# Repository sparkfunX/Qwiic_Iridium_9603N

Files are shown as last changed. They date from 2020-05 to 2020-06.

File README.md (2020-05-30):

# Qwiic Iridium 9603N

Iridium 9603N in Qwiic format (with I2C connectivity)

Qwiic Iridium 9603N (SPX-16394)

[Qwiic Iridium 9603N (SPX-16394)](https://www.sparkfun.com/products/16394)

## Repository Contents

- **/Hardware** - Eagle PCB, SCH and LBR design files
- **/Firmware** - Arduino code which comes pre-programmed onto the board
- **LEARN.md** contains a description of the Qwiic Iridium 9603N hardware
- **LICENSE.md** contains the licence information

## Arduino Examples

You will find a complete set of Arduino Examples for the Qwiic Iridium 9603N built into the [SparkFun IridiumSBD I2C Arduino Library](https://github.com/sparkfun/SparkFun_IridiumSBD_I2C_Arduino_Library).
Look for the [I2C_Examples__Qwiic_Iridium](https://github.com/sparkfun/SparkFun_IridiumSBD_I2C_Arduino_Library/tree/master/examples).

## Acknowledgements

This project relies upon [Spence Konde's ATTinyCore](https://github.com/SpenceKonde/ATTinyCore) for the ATtiny841.
Spence's work is gratefully acknowledged.

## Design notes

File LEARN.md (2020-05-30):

# Qwiic Iridium 9603N : LEARN

Qwiic Iridium 9603N (SPX-16394)

[Qwiic Iridium 9603N (SPX-16394)](https://www.sparkfun.com/products/16394)

## What is it?

The Qwiic Iridium 9603N is a breakout for the [Iridium 9603N Short Burst Data transceiver](https://www.iridium.com/products/iridium-9603/)
which can be used to send and receive _short_ messages (340 bytes transmitted, 270 bytes received) to and from _anywhere_ on Earth.

The 9603N has a serial (UART) interface which is great for many applications, but by no means all. The Qwiic Iridium 9603N uses an
[ATtiny841 AVR microcontroller](https://www.microchip.com/wwwproducts/en/ATTINY841) to bridge the serial interface to I2C,
allowing you to easily add Iridium communication to all Qwiic projects.

The key components of the Qwiic Iridium 9603N are:

## Iridium 9603N SBD Transceiver

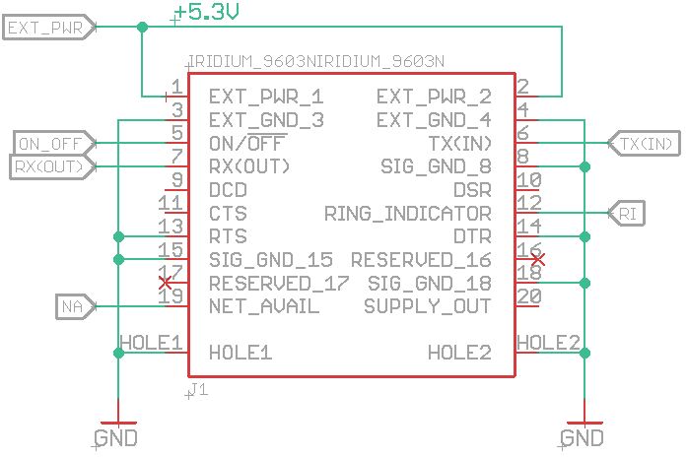
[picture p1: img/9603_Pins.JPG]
9603_Pins


The 9603N transceiver is a 5V device but has 3.3V serial (UART) and Input/Ouput pins. The serial interface uses an old-school "AT"
command set to send and receive messages. The I/O pins control its operation. The Qwiic Iridium 9603N connects to:

- Pins 1 & 2: these are connected to the 5.3V supply from the supercapacitors via the ADM4210 and N-FET.
- Pin 5: enables or disables the 9603N. High enables the 9603N, low disables it.
- Pin 6: is the serial data transmit _input_. The ATtiny841 serial transmit is connected to this pin.
- Pin 7: is the serial receive data _output_. This connects to the ATtiny841 serial receive pin.
- Pin 12: is the Ring Indicator. This pin will pulse low twice when a new 'Mobile Terminated' message is waiting to be downloaded.
- Pin 13: is the serial Request To Send input. This needs to be pulled low to allow serial communication to take place.
- Pin 14: is the serial Data Terminal Ready input. This too need to be pulled low.
- Pin 19: will be high when the Iridium network is available and the 9603N is able to receive the ring channel.

The ATtiny is connected to the I/O pins to form an I2C to serial bridge.

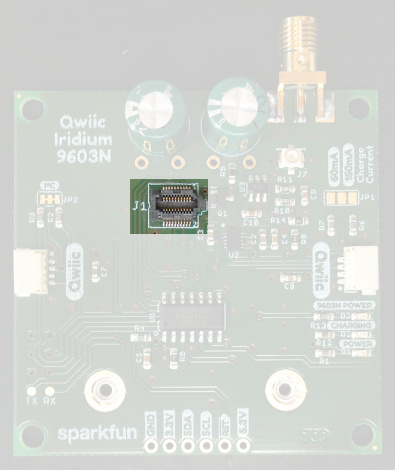
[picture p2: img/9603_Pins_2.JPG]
9603_Pins_2


The full AT command reference can be found [here](http://www.rock7mobile.com/downloads/IRDM_ISU_ATCommandReferenceMAN0009_Rev2.0_ATCOMM_Oct2012.pdf).

## LTC3225 Supercapacitor Charger and ADM4210 Current Limiter

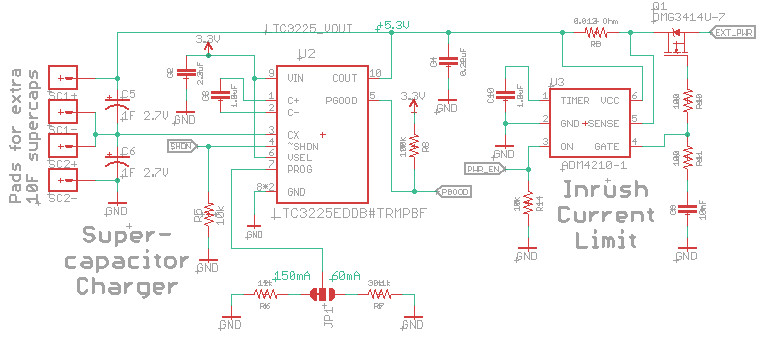
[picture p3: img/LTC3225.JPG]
LTC3225


The 9603N requires a power input of 5VDC +/- 0.5V. The power consumption at 5VDC is:

- 34mA average when idle
- 156mA peak when idle
- 39mA average during receive
- 156mA peak during receive
- 145mA average during transmit
- 1.3A peak during transmit
- The average current draw during a complete receive/transmit cycle is 158mA

The Qwiic Iridium 9603N uses an [LTC3225](https://www.analog.com/en/products/ltc3225.html) supercapacitor charger to meet these power needs.
When powered by 3.3V from the Qwiic interface, it charges a pair of supercapacitors to 5.3V. These capacitors deliver the 1.3A peak
current draw when the 9603N transmits.

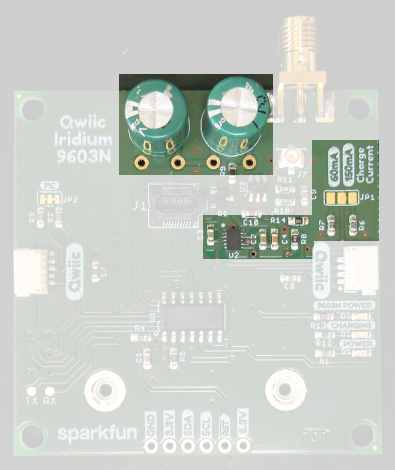
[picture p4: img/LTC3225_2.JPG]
LTC3225_2


The LTC3225 charge current is adjustable up to a maximum of 150mA. When set to the full 150mA, the LTC3225 can match the 145mA average current
drawn by the 9603N during transmit. This means that 1 Farad supercapacitors are adequate as they only need to hold enough charge to meet the
9603N's peak current draw during the very brief (8.3ms) transmit bursts.

The LTC3225 has an efficiency of approximately 75% when powered from 3.3V. This means the current drawn from the Qwiic interface is
approximately 200mA when charging the supercapacitors.

If you want to power the Qwiic Iridium 9603N from a low current source, e.g. solar panels, the charge current can be reduced to 60mA by
changing the JP1 jumper link. The current draw from the Qwiic interface falls to approximately 80mA. The 60mA charge current is enough
to offset the average current draw during receive, but bigger supercapacitors are needed to deliver the average current draw during a complete
receive/transmit cycle. So, if you do change the charge current to 60mA, you will also need to solder additional 10 Farad supercapacitors on to
the rear of the PCB using the solder pads provided.

The datasheet for the 9603N states that it can have a very low impedance when unpowered, leading to a large inrush current when the power is enabled.
The power supply circuit needs to limit the inrush current to a maximum of 4 Amps. To achieve this, the Qwiic Iridium 9603N uses an
[ADM4210-1](https://www.analog.com/en/products/adm4210.html) which can sense the current via R9 and limit it by changing Q1's Gate voltage.
The ADM4210 will limit the current when the voltage across R9 exceeds 50mV (4 Amps * 0.012 Ohms).

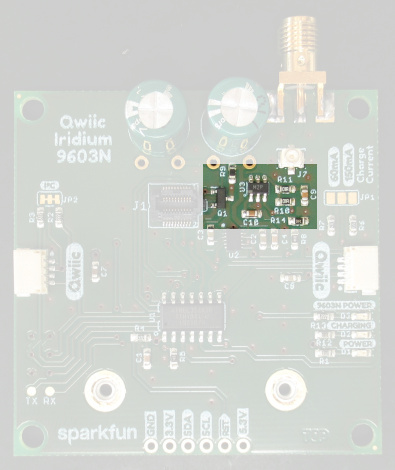
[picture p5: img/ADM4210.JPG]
ADM4210


The connections between the ATtiny841, LTC3225 and the ADM4210 are:

- !SHDN (LTC3225 Pin 6, ATtiny Pin 2) is used to enable or disable the LTC3225. Pulling this pin high enables it, low disables it.
- PGOOD (LTC3225 Pin 5, ATtiny Pin 5) goes high when the supercapacitors are 94% charged. This pin is used to illuminated LED D2; D2 lights up when the capacitors
are _charging_.
- PWR_EN (ADM4210 Pin 3, ATtiny Pin 10) is used to enable or disable the ADM4210. Pulling PWR_EN high enables power for the 9603N, low disables it.

The power-up sequence is:

- Enable the LTC3225 by pulling !SHDN high
- Wait until PGOOD goes high (LED D2 goes out)
- Enable 9603N power by pulling PWR_EN high

[The Iridium SBD I2C library](https://github.com/sparkfun/SparkFun_IridiumSBD_I2C_Arduino_Library) contains all of the functions you need to control the
Qwiic Iridium 9603N. The library contains several I2C examples including "Beacon_I2C" which demonstrates how to interface the Qwiic Iridium 9603N with
(e.g.) a [SparkFun SAM-M8Q breakout](https://www.sparkfun.com/products/15210)
or [ZOE-M8Q breakout](https://www.sparkfun.com/products/15193) to form an I2C GPS + Iridium beacon or tracker.

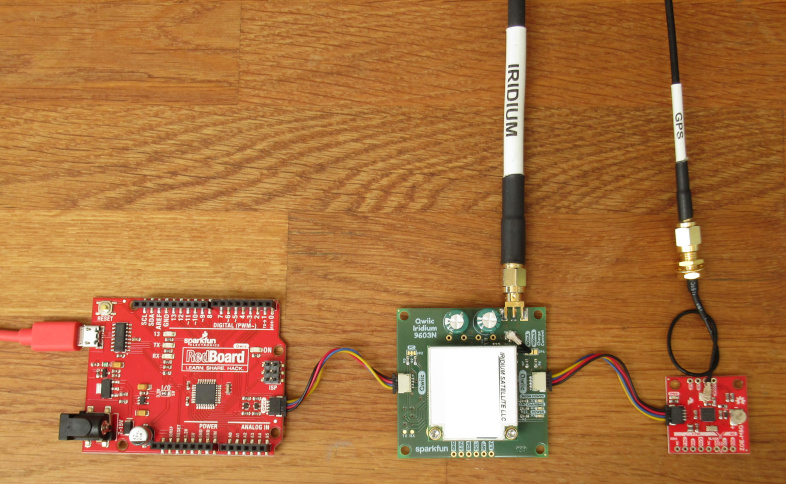
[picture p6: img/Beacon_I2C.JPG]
Beacon_I2C


The power control functions in the library are:

- _enableSuperCapCharger(true)_ will enable the LTC3225 by pulling !SHDN high
- _checkSuperCapCharger()_ will return true when PGOOD has gone high
- _enable9603Npower(true)_ will enable power for the 9603N by pulling PWR_EN high
- _enable841lowPower(true)_ will enable the ATtiny841's low power mode, substantially reducing the standby current

## ATtiny841

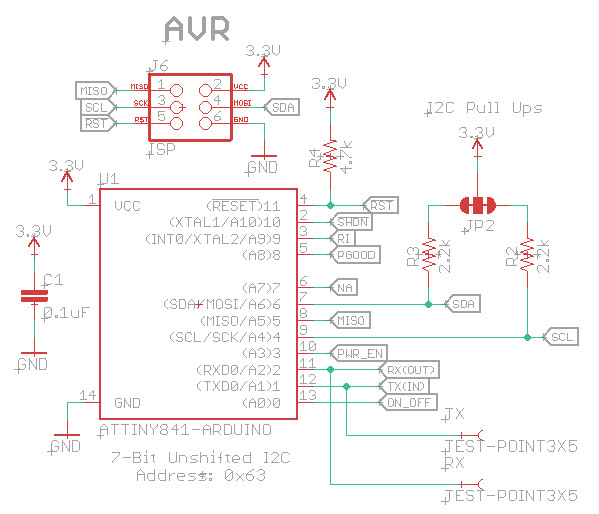
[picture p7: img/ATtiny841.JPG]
ATtiny841


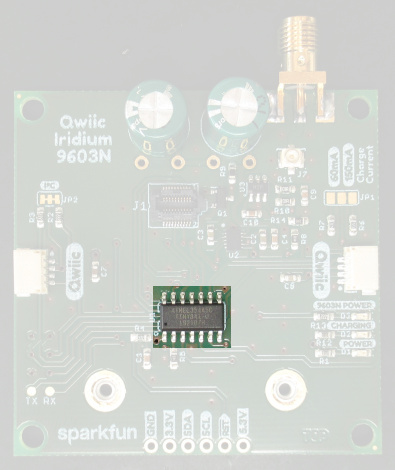
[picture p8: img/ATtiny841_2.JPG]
ATtiny841_2


The ATtiny841 is an enhanced version of the popular ATtiny84. It includes hardware support for both I2C and Serial which is vital when using it as an
I2C to Serial bridge. (Software serial isn't up to the job.)

Spence Konde has written a comprehensive library called [ATTinyCore](https://github.com/SpenceKonde/ATTinyCore) which provides full support for the ATtiny841.
You will need to use version 1.3.0 of the library (or later) as it includes
[one important fix](https://github.com/SpenceKonde/ATTinyCore/commit/0d17000a645234bb540b82086debf39ccb87f172) which the Qwiic Iridium 9603N needs.

[The Iridium SBD I2C library](https://github.com/sparkfun/SparkFun_IridiumSBD_I2C_Arduino_Library) contains high level functions which you can call to control and communicate with
the Qwiic Iridium 9603N. They do all of the heavy lifting for you. However, the following sections will be useful if you want to understand how the I2C interface works
so you can develop your own Wire functions should you want to.

## I2C (Wire) Interface

The Qwiic Iridium 9603N emulates a slave I2C device with a fixed address of 0x63. You can change the address but only by editing the
[Arduino firmware](Firmware/Qwiic_Iridium_9603N_ATtiny841/Qwiic_Iridium_9603N_ATtiny841.ino#L102).

The code in the ATtiny841 emulates three read/write 'registers':

- IO_REG (0x10) : the Input/Output register which is used to read and write the I/O pins
- LEN_REG (0xFD) : this register returns the number of bytes waiting to be read from the serial buffer. The buffer length is returned in MSB,LSB format.
- DATA_REG (0xFF) : this register allows serial data to be written to and read from the 9603N

### IO_REG

To read the I/O pins, the I2C Master needs to:

```
Wire.beginTransmission(0x63); // Open communication with the Qwiic Iridium 9603N
Wire.write(0x10); // Point to the IO register
Wire.endTransmission(); // Send data and release the bus
Wire.requestFrom(0x63, 1); // Request one byte from the IO register
if (Wire.available())
{
  uint8_t io_pins = Wire.read(); // Read the IO register
}
```

The WireS library for the 841 doesn't like it if the Master holds the bus between write and requestFrom, so don't use _endTransmission(false);_

The bit definitions for the IO_REG are:

- Bit 7: Not Used
- Bit 6: LOW_PWR - Read/Write - this bit enables/disables the ATtiny841's low power mode. Writing 1 to this bit enables low power mode
- Bit 5: PGOOD - Read Only - this bit will be high when the LTC3225 PGOOD signal is high
- Bit 4: NA - Read Only - this bit will be high when the 9603N Network Available pin is high
- Bit 3: RI - Read/Write - this bit is a flag which is set when the 9603N Ring Indicator pin pulses low. The flag can be cleared by writing a 0 to this bit
- Bit 2: ON_OFF - Read/Write - this bit controls the 9603N on/off pin (Pin 5). Writing a 1 to this bit enables the 9603N
- Bit 1: PWR_EN - Read/Write - this bit controls the PWR_EN signal which enables power to the 9603N via the ADM4210. Writing 1 to this bit enables the 9603N power
- Bit 0: SHDN - Read/Write - this bit controls the LTC3225 !SHDN signal to enable/disable the supercapacitor charger. Writing 1 to this bit enables the LTC3225

When writing to the IO_REG, you will need to use a read-modify-write approach: read the IO_REG, set or clear the appropriate bit(s), write the value back to the IO_REG.
E.g. to enable the LTC3225, the Master needs to:

```
Wire.beginTransmission(0x63); // Open communication with the Qwiic Iridium 9603N
Wire.write(0x10); // Point to the IO register
Wire.endTransmission(); // Send data and release the bus
Wire.requestFrom(0x63, 1); // Request one byte from the IO register
uint8_t io_pins = Wire.read(); // Read the IO register
io_pins |= 0x01; // Set the SHDN bit to enable the LTC3225
Wire.beginTransmission(0x63); // Open communication with the Qwiic Iridium 9603N
Wire.write(0x10); // Point to the IO register
Wire.write(io_pins); // Update the pins
Wire.endTransmission(); // Send data and release the bus
```

### LEN_REG

The serial length register indicates how many bytes are available in the Qwiic Iridium 9603N's serial buffer. The length is returned as two bytes in MSB,LSB format.

To read the buffer length, the I2C Master needs to:

```
uint16_t bytesAvailable = 0;
Wire.beginTransmission(0x63); // Open communication with the Qwiic Iridium 9603N
Wire.write(0xFD); // Point to the length register
Wire.endTransmission(); // Send data and release the bus
Wire.requestFrom(0x63, 2); // Request two bytes from the length register
if (Wire.available() >= 2)
{
  uint8_t msb = Wire.read(); // Read the length MSB
  uint8_t lsb = Wire.read(); // Read the length LSB
  bytesAvailable = (((uint16_t)msb) << 8) | (uint16_t)lsb; // Update bytesAvailable
}
```

Reading serial data from the DATA_REG needs to be done eight bytes at a time (if there are more than eight bytes available) due to limitations in the way the
way Wire.onRequest works. See below for details.

### DATA_REG

The serial data register is used to send data to and receive data from the 9603N.

To write serial data to the 9603N, the I2C Master simply needs to:

```
Wire.beginTransmission(0x63); // Open communication with the Qwiic Iridium 9603N
Wire.write(0xFF); // Point to the data register
Wire.print(str); // Write the string
Wire.endTransmission(); // Send data and release the bus
```

Take care not to send more than 32 bytes in one go or you will overflow the ATtiny's I2C buffer! Use multiple writes as required.

Reading serial data is a little more complex as the Wire.onRequest code in the ATtiny does not know how many bytes are being requested, simply that _some_ data is being requested.
For the Qwiic Iridium 9603N, we define that the Master will request data eight bytes at a time (if there are eight or more bytes available in the serial buffer).

A complete read cycle would be:

```
uint16_t bytesAvailable = 0;
Wire.beginTransmission(0x63); // Open communication with the Qwiic Iridium 9603N
Wire.write(0xFD); // Point to the length register
Wire.endTransmission(); // Send data and release the bus
Wire.requestFrom(0x63, 2); // Request two bytes from the length register
if (Wire.available() >= 2)
{
  uint8_t msb = Wire.read(); // Read the length MSB
  uint8_t lsb = Wire.read(); // Read the length LSB
  bytesAvailable = (((uint16_t)msb) << 8) | (uint16_t)lsb; // Update bytesAvailable
}
while (bytesAvailable > 8) // If there are more than 8 bytes waiting to be read
{
  Wire.requestFrom(0x63, 8); // Request 8 bytes from the data register
  while (Wire.available())
  {
    uint8_t data_byte = Wire.read(); // Read the data
    // Store the data byte
  }
  bytesAvailable -= 8; // Decrease bytesAvailable by 8
}
if (bytesAvailable > 0) // If there are some bytes waiting to be read
{
  Wire.requestFrom(0x63, bytesAvailable); // Request the remaining bytes from the data register
  while (Wire.available())
  {
    uint8_t data_byte = Wire.read(); // Read the data
    // Store the data byte
  }
}
```

The code in the ATtiny keeps its own copy of how many bytes were in the serial buffer when the length register was read, so it knows how many bytes to send
to the Master even if new serial data from the 9603N arrives part way through.

## ATTinyCore

The [Firmware folder](../../tree/master/Firmware) contains the code for the ATtiny841.

The Qwiic Iridium 9603N relies upon Spence Konde's [ATTinyCore](https://github.com/SpenceKonde/ATTinyCore) to provide support for the ATtiny841.

When compiling the code:
- Set Board to ATtiny441/841 (No bootloader)
- Set Chip to ATtiny841
- Set Clock to 8MHz(internal)
- Set BOD Level to BOD Enabled 1.8V
- Set BOD Mode (Active) and (Sleep) to BOD Disabled
- Set Save EEPROM to EEPROM Not Retained
- **Set Pin Mapping to Clockwise**
- **Set Wire Modes to Slave Only**
- Set millis()/micros():"Enabled" to Enabled

The ATtiny841 is delivered with the CKDIV8 bit programmed, which will make the 841 run at 1MHz instead of 8MHz. You will need to use (e.g.) AVRDUDESS to read and then
set the fuses to correct this:

- Set the L (Low) fuse byte to **0xC2**
- Set the H (High) fuse byte to 0xDF
- Set the E (Extended) fuse byte to 0xFF

Enjoy!

_Your friends at SparkFun_

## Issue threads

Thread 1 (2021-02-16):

3.3 V rail voltage drops during charging

adamgarbo, 2021-02-16:
Hi @PaulZC

I recently concluded a successful 11-day test of the Qwiic Iridium 9603N + MicroMod Data Logging Carrier Board + Artemis Processor. Temperatures in Canada were chilly again, dropping to -25°C, and it was a good opportunity to stress test the components in the cold.

I realized I had never measured the voltage of the 3.3 V rail when the Qwiic Iridium was powering up. I was surprised to see that when charging (@ 150 mA), the Qwiic Iridium hammers the 3.3 V bus, causing it to drop to 2.9 V. I observed the same behaviour when connected to both an MMDLCB (powered by a 3.7 V LiPo) and a Qwiic Micro (3.3 V rail powered by a SparkFun Buck-Boost).

Is this expected behaviour for the Qwiic Iridium 9603N? If so, do you anticipate this voltage drop would cause any issues for other devices on the I2C bus? 

Cheers,
Adam

PaulZC, 2021-02-17:
Hi Adam (@adamgarbo ),
Thanks for letting me know. I will dig into this as soon as time permits.
Best wishes,
Paul

adamgarbo, 2021-02-19:
Thanks, @PaulZC!

I should note that I'm encountering this issue with V1 of the Qwiic Iridium 9603N. Did the power circuity change in V2?

Cheers,
Adam

adamgarbo, 2021-02-19:
A quick test with a SparkFun Qwiic Micro + Qwiic Iridium 9603N. The 3.3 V rail is powered by a SparkFun BuckBoost connected to a 12 V battery.

The Buck-Boost can output up to 2 A, which the Qwiic Iridium should never get close to. Same behaviour observed with a Pololu 3.3V 600 mA step-down regulator.

Putting it on scope reveals there is definitely something strange going on.

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

PaulZC, 2021-02-20:
Hi @adamgarbo ,
Thanks for this.
I wouldn't describe the trace as 'strange'. That's exactly what I would expect to see. A long period of capacitor charging, followed by short bursts of capacitor charging while the Iridium modem is on but not transmitting, followed by a longer burst to top the capacitors back up during and after the transmission.
What is unexpected is the size of the voltage drop. I would have expected it to be much smaller than that.
How are you connecting everything? Qwiic cable? Hard-soldered wires/connectors? Or breadboard + jumper wires?
I will dig into this when I get time - promise.
Best wishes,
Paul

adamgarbo, 2021-02-20:
Hi @PaulZC,

I agree! The output of the oscilloscope is expected, but not the magnitude of the voltage drops. I just finished performing a dozen tests of different combinations of components and will update this comment once I finish reviewing the data. The two biggest culprits right now are the [SparkFun breadboards](https://www.sparkfun.com/products/12615) I recently purchased and the Qwiic Power Switch. When everything is connected directly through Qwiic cables, the voltage drop issues seem to disappear, unless the Qwiic Iridium 9603N is behind the Qwiic Power Switch.

Cheers,
Adam

adamgarbo, 2021-02-21:
Hi @PaulZC,

Well, I think I've had enough of measuring voltages! Based on the graphs shown below, I believe we can draw a few main conclusions:

1) The Qwiic Iridium 9603N should never be placed behind the Qwiic Power Switch. This results in the most significant voltage drops (Tests 1, 2, 5, 6).
2) The SparkFun Buck-Boost does not appear to be suitable for replacing the Qwiic Micro's AP2112 regulator. It does not handle the load of the Qwiic Iridium 9603N (or RockBLOCK) very well. The 5V USB battery and AP2112 LDO results in a much stabler voltage (see Test 8)
3) The SparkFun Breadboard is also causing increased voltage drops when compared to using the Qwiic connectors, even with minimal length 22 AWG jumper wires. Tests 4 vs 8 is a good example of this.

Based on these test results, I don't believe there's actually any issue with Qwiic Iridium 9603N. The problem is really with everything else!

I'm a little worried that because I don't see a ring carrier signal that the current draw of the Qwiic Iridium 9603N may not be reflective of a real work scenario, so I may try measuring the voltage outside in the snow.

I'll leave this issue open until I perform the same tests on the MicroMod Data Logging Carrier Board. I suspect I'll encounter much the same results.

Cheers,
Adam

## Test Configuration

All tests used the following SparkFun Qwiic components:
* Qwiic Micro SAMD21
* RV8803 RTC
* BME280
* Qwiic Power Switch
* SAM-M8Q
* Qwiic Iridium 9603N

**Circuit design/wiring:**
1. SparkFun breadboard and 22 AWG jumper wires cut to a minimum length, or
2. Qwiic connectors

**Power sources:**
1. SparkFun Buck-Boost @3.3V powered from 12 V battery connected directly to 3.3V rail
2. 10 Ah 5V USB battery connected direcly to Qwiic Micro's USB port (uses AP2112 LDO)

**Measurements:**
* PicoScope 4227 oscilloscope
* Channel A (blue): 3.3 V rail or directly on Qwiic 3.3V/GND pins
* Channel B (red): 3.3V/GND pins of Qwiic Iridium 9603N
* Oscilloscope output saved to CSV and plotted in Python

**Test 1:**
* Buck-Boost @3.3V
* SparkFun breadboard + jumper wires
* Qwiic Iridium 9603N behind Qwiic Power Switch (QPS)
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

**Test 2:**
* 5V USB battery
* SparkFun breadboard + jumper wires
* Qwiic Iridium 9603N behind QPS
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

**Test 3:**
* Buck-Boost @3.3V
* SparkFun breadboard + jumper wires
* Qwiic Iridium 9603N in front QPS
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

**Test 4:**
* 5V USB battery
* SparkFun breadboard + jumper wires
* Qwiic Iridium 9603N in front QPS
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

**Test 5:**
* Buck-Boost @3.3V
* Qwiic connectors
* Qwiic Iridium 9603N behind QPS
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

**Test 6:**
* 5V USB battery
* Qwiic connectors
* Qwiic Iridium 9603N behind QPS
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

**Test 7:**
* Buck-Boost @3.3V
* Qwiic connectors
* Qwiic Iridium 9603N in front of QPS
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

**Test 8:**
* 5V USB battery
* Qwiic connectors
* Qwiic Iridium 9603N in front of QPS
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

PaulZC, 2021-02-22:
Hi Adam (@adamgarbo ),
Nice very methodical work! ;-) Thank you.
The Qwiic Power Switch drop is a surprise. The breadboard + jumpers less so. (Think about the **tiny** contact area between the breadboard 'fingers' or 'jaws' and your solid-core jumper wires.)
The QPS uses a DMG2305 P-FET and looking at the datasheet the R<sub>DS(ON)</sub> varies with both temperature and V<sub>GS</sub>. But I would expect it to be around 50mOhms at 3.3V and room temperature. If the Qwiic Iridium is drawing around 300mA (roughly double the charging current), the voltage drop across the FET should be around 15mV, not ~ten times that... Maybe we're not driving the gate hard enough? I wonder what would happen if R5 were changed to 100R or 10R?
I will investigate when I get time, but like you say, the Qwiic Iridium itself appears to be behaving as expected.
Thanks!
Paul

adamgarbo, 2021-02-22:
Thanks, Paul!

I'm happy to create a separate issue on the QPS repository but it's not a high priority.

Regarding wiring, wouldn't the "jaws" of the breadboard technically have more surface area contact with the AWG 22 jumper wire than the Qwiic JST connector/28 AWG wire? SparkFun doesn't have any information on the max current rating of their breadboards, but I would expect that they should be able to handle ~0.3 A without any difficulty. Given this, I suspect that the breadboard is also the cause of the problems I was having when trying to power a RockBLOCK at ~450 mA.

Cheers,
Adam

Closed 2021-02-22.

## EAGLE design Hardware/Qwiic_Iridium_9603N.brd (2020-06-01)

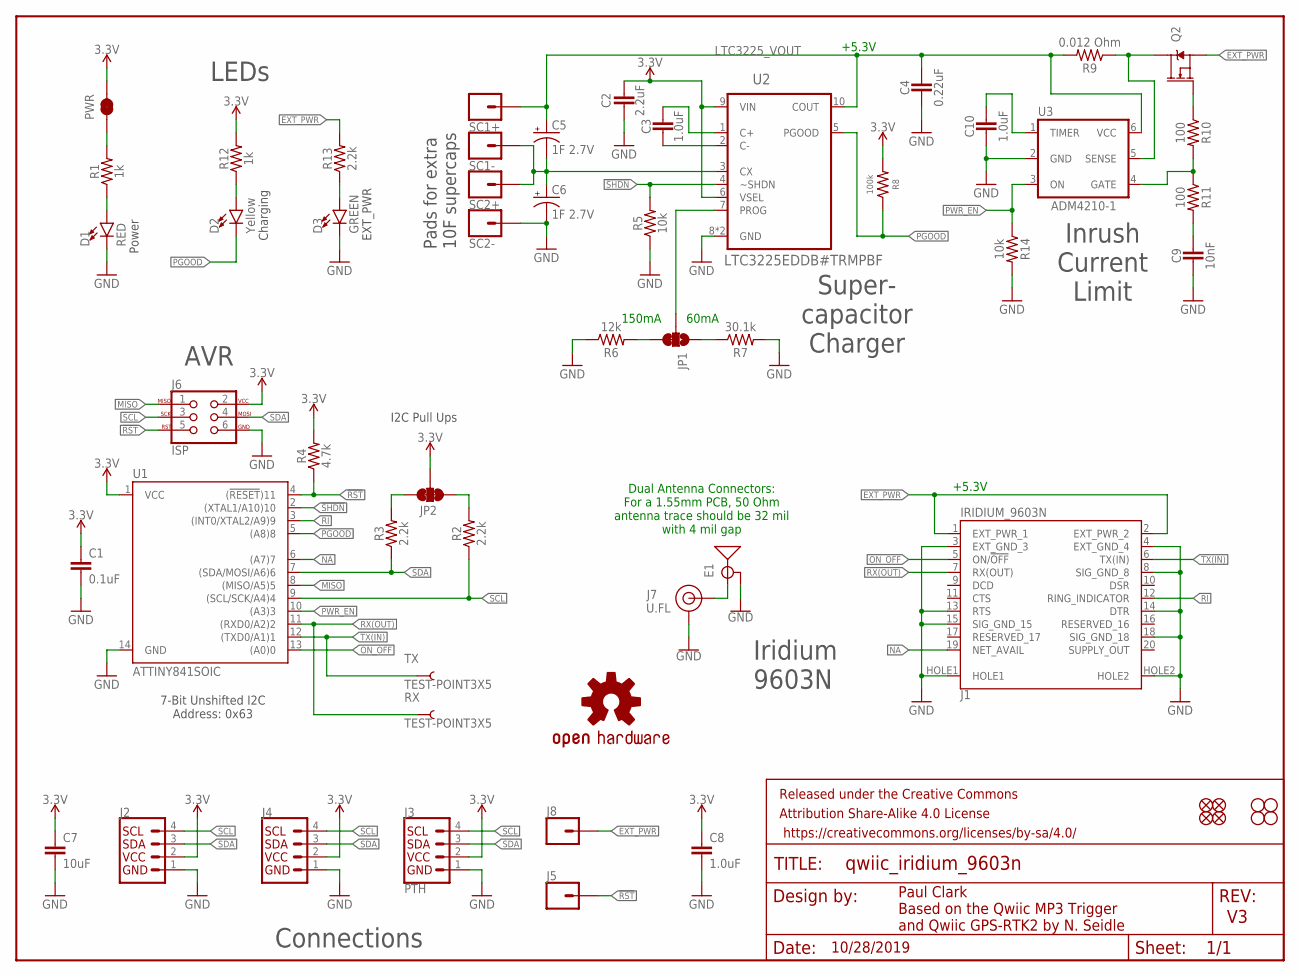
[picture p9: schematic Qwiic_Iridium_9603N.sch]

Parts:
C1: 0.1uF; 0603
C2: 2.2uF; 0603
C3, C8, C10: 1.0uF; 0603
C4: 0.22uF; 0603
C5, C6: 1F 2.7V; CPOL-RADIAL-1F-2.7V
C7: 10uF; 0603
C9: 10nF; 0603
D1: RED; LED-0603
D2: Yellow; LED-0603
D3: GREEN; LED-0603
E1: ANTENNA-GROUNDEDEDGE_SMA; SMA-EDGE
FRAME1: FRAME-LETTER; CREATIVE_COMMONS
J1: IRIDIUM_9603N
J2, J4: QWIIC_CONNECTORJS-1MM; JST04_1MM_RA
J3: PTH; 1X04_NO_SILK
J5, J8: CONN_01PTH_NO_SILK_YES_STOP; 1X01_NO_SILK
J6: ISP; 2X3_TEST_POINTS
J7: U.FL
JP1: JUMPER-SMT_3_1-NC_TRACE_SILK; SMT-JUMPER_3_1-NC_TRACE_SILK
JP2: JUMPER-SMT_3_2-NC_TRACE_SILK; SMT-JUMPER_3_2-NC_TRACE_SILK
JP3, JP4, JP9, JP10: STAND-OFF
JP5, JP6, JP7, JP8: FIDUCIAL1X2; FIDUCIAL-1X2
LOGO1: OSHW-LOGOMINI; OSHW-LOGO-MINI
PWR: JUMPER-SMT_2_NC_TRACE_SILK; SMT-JUMPER_2_NC_TRACE_SILK
Q2: 5.8A/30V/35mΩ; SOT23-3
R1, R12: 1k; 0603
R2, R3, R13: 2.2k; 0603
R4: 4.7k; 0603
R5, R14: 10k; 0603
R6: 12k; 0603
R7: 30.1k; 0603
R8: 100k; 0603
R9: 0.012 Ohm; 0603
R10, R11: 100; 0603
RX: TEST-POINT3X5; PAD.03X.05
SC1+, SC1-, SC2+, SC2-: CONN_01PTH_NO_SILK_YES_STOP; 1X01_NO_SILK
TX: TEST-POINT3X5; PAD.03X.05
U1: ATTINY841SOIC; ATTINY841
U2: LTC3225EDDB#TRMPBF; DFN300X200-10L
U3: ADM4210-1; TSOT6

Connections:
3.3V: C1.1, C2.1, C7.1, C8.1, J2.2, J3.2 (VCC), J4.2, J6.2, JP2.2, PWR.2, R4.2, R8.2, R12.2, U1.1 (VCC), U2.6 (VSEL), U2.9 (VIN)
!RST: J5.1, J6.5, R4.1, U1.4 ((!RESET!)11)
!SHDN: R5.2, U1.2 ((XTAL1/A10)10), U2.4 (~SHDN)
EXT_PWR: J1.1 (EXT_PWR_1), J1.2 (EXT_PWR_2), J8.1, Q2.2 (S), R13.2
GND: C1.2, C2.2, C4.2, C6.-, C7.2, C8.2, C9.2, C10.2, D1.C, D3.C, E1.GND@0 (GND), E1.GND@1 (GND), E1.GND@2 (GND), E1.GND@3 (GND), J1.3 (EXT_GND_3), J1.4 (EXT_GND_4), J1.8 (SIG_GND_8), J1.13 (RTS), J1.14 (DTR), J1.15 (SIG_GND_15), J1.18 (SIG_GND_18), J1.HOLE1, J1.HOLE2, J2.1, J3.1 (GND), J4.1, J6.6, J7.1 (GND), J7.2 (GND), R5.1, R6.1, R7.2, R14.2, SC2-.1, U1.14 (GND), U2.8 (GND), U2.11 (GND), U3.2 (GND)
LTC3225_VOUT: C4.1, C5.+, R9.2, SC1+.1, U2.10 (COUT), U3.6 (VCC)
MISO: J6.1, U1.8 ((MISO/A5)5)
unnamed: C5.-, C6.+, SC1-.1, SC2+.1, U2.3 (CX)
unnamed: JP1.3, R6.2
unnamed: D1.A, R1.1
unnamed: JP1.1, R7.1
unnamed: D2.A, R12.1
unnamed: D3.A, R13.1
unnamed: E1.SIG (SIGNAL), J7.FEED (SIGNAL)
unnamed: Q2.3 (D), R9.1, U3.5 (SENSE)
unnamed: C3.2, U2.2 (C-)
unnamed: C3.1, U2.1 (C+)
unnamed: JP1.2, U2.7 (PROG)
unnamed: Q2.1 (G), R10.1
unnamed: R10.2, R11.1, U3.4 (GATE)
unnamed: C9.1, R11.2
unnamed: C10.1, U3.1 (TIMER)
unnamed: PWR.1, R1.2
NA: J1.19 (NET_AVAIL), U1.6 ((A7)7)
ON_OFF: J1.5 (ON/!OFF!), U1.13 ((A0)0)
PGOOD: D2.C, R8.1, U1.5 ((A8)8), U2.5 (PGOOD)
PWR_EN: R14.1, U1.10 ((A3)3), U3.3 (ON)
RI: J1.12 (RING_INDICATOR), U1.3 ((INT0/XTAL2/A9)9)
RX(OUT): J1.7 (RX(OUT)), RX.P$1, U1.11 ((RXD0/A2)2)
SCL: J2.4, J3.4 (SCL), J4.4, J6.3, R2.1, U1.9 ((SCL/SCK/A4)4)
SCL_PU1: JP2.1, R2.2
SDA: J2.3, J3.3 (SDA), J4.3, J6.4, R3.1, U1.7 ((SDA/MOSI/A6)6)
SDA_PU1: JP2.3, R3.2
TX(IN): J1.6 (TX(IN)), TX.P$1, U1.12 ((TXD0/A1)1)

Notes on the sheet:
Paul Clark Based on the Qwiic MP3 Trigger and Qwiic GPS-RTK2 by N. Seidle
Power
7-Bit Unshifted I2C Address: 0x63
I2C Pull Ups
AVR
Connections
+5.3V
150mA
60mA
Pads for extra 10F supercaps
Super- capacitor Charger
Charging
EXT_PWR
Iridium 9603N
Dual Antenna Connectors: For a 1.55mm PCB, 50 Ohm antenna trace should be 32 mil with 4 mil gap
LEDs
Inrush Current Limit
10/28/2019

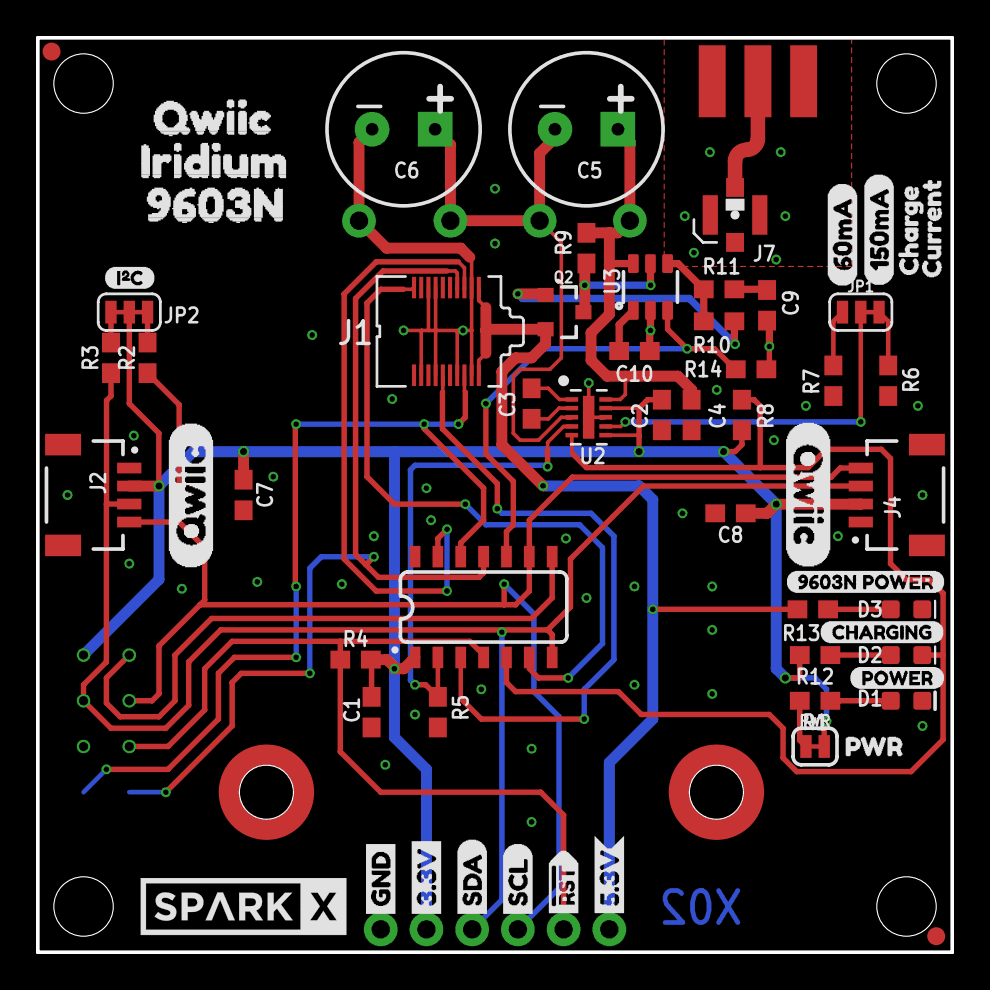
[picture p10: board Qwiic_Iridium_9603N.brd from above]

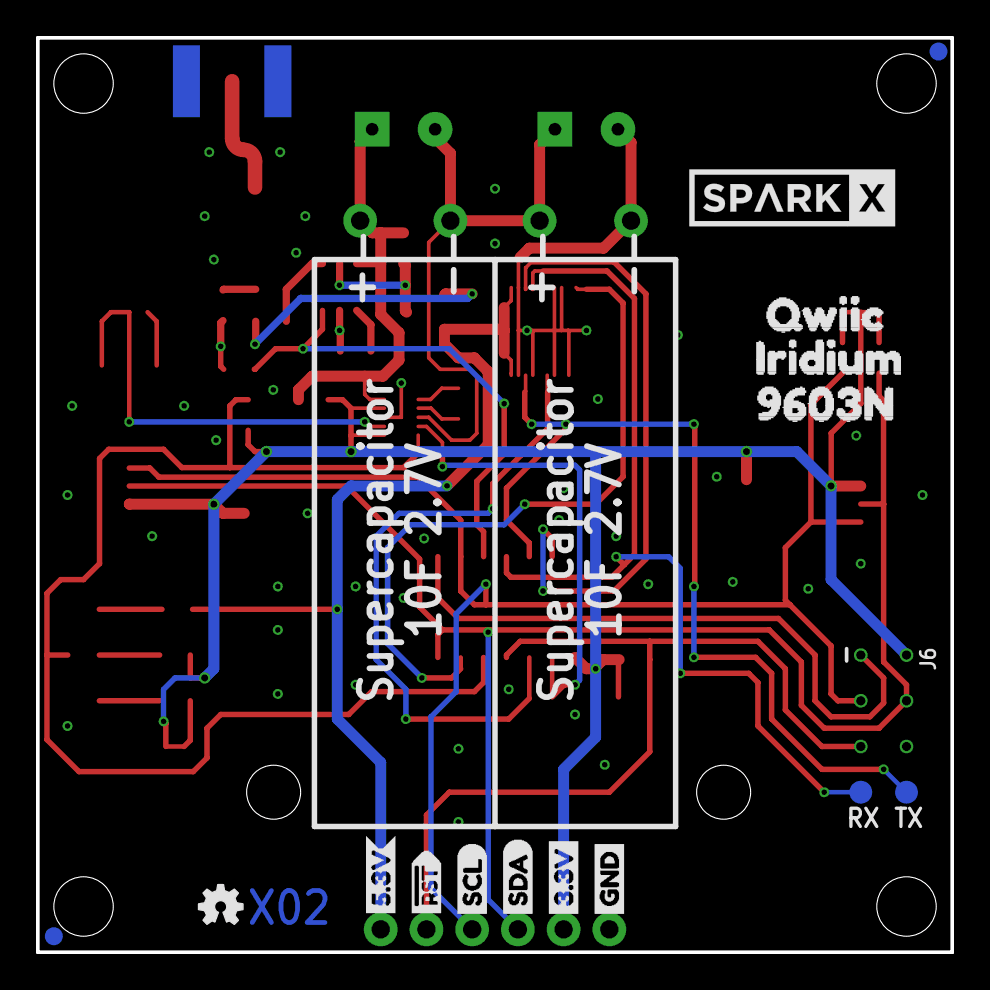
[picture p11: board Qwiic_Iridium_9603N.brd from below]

Board: 2 copper layers, 50.8 x 50.8 mm, 90 parts (16 on the bottom side), 34 nets.

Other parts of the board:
U$1: 60MA0
U$2: POWER0
U$3, U$22: GND1
U$4, U$21: 3#3V2
U$5, U$27: SDA8
U$6, U$26: SCL9
U$7, U$16: RST#-[>
U$8: I_SUPER2_C-()-03
U$9: CHARGING0
U$10: 9603N_POWER0
U$11, U$32: 5#3V0
U$12, U$17, U$23, U$25: QWIIC0
U$13: 150MA0
U$14: CHARGE0
U$15: CURRENT0
U$18, U$19: IRIDIUM0
U$20, U$24: 9603N0
U$29, U$30: SPARKX-LARGE
U$31: _PWR1

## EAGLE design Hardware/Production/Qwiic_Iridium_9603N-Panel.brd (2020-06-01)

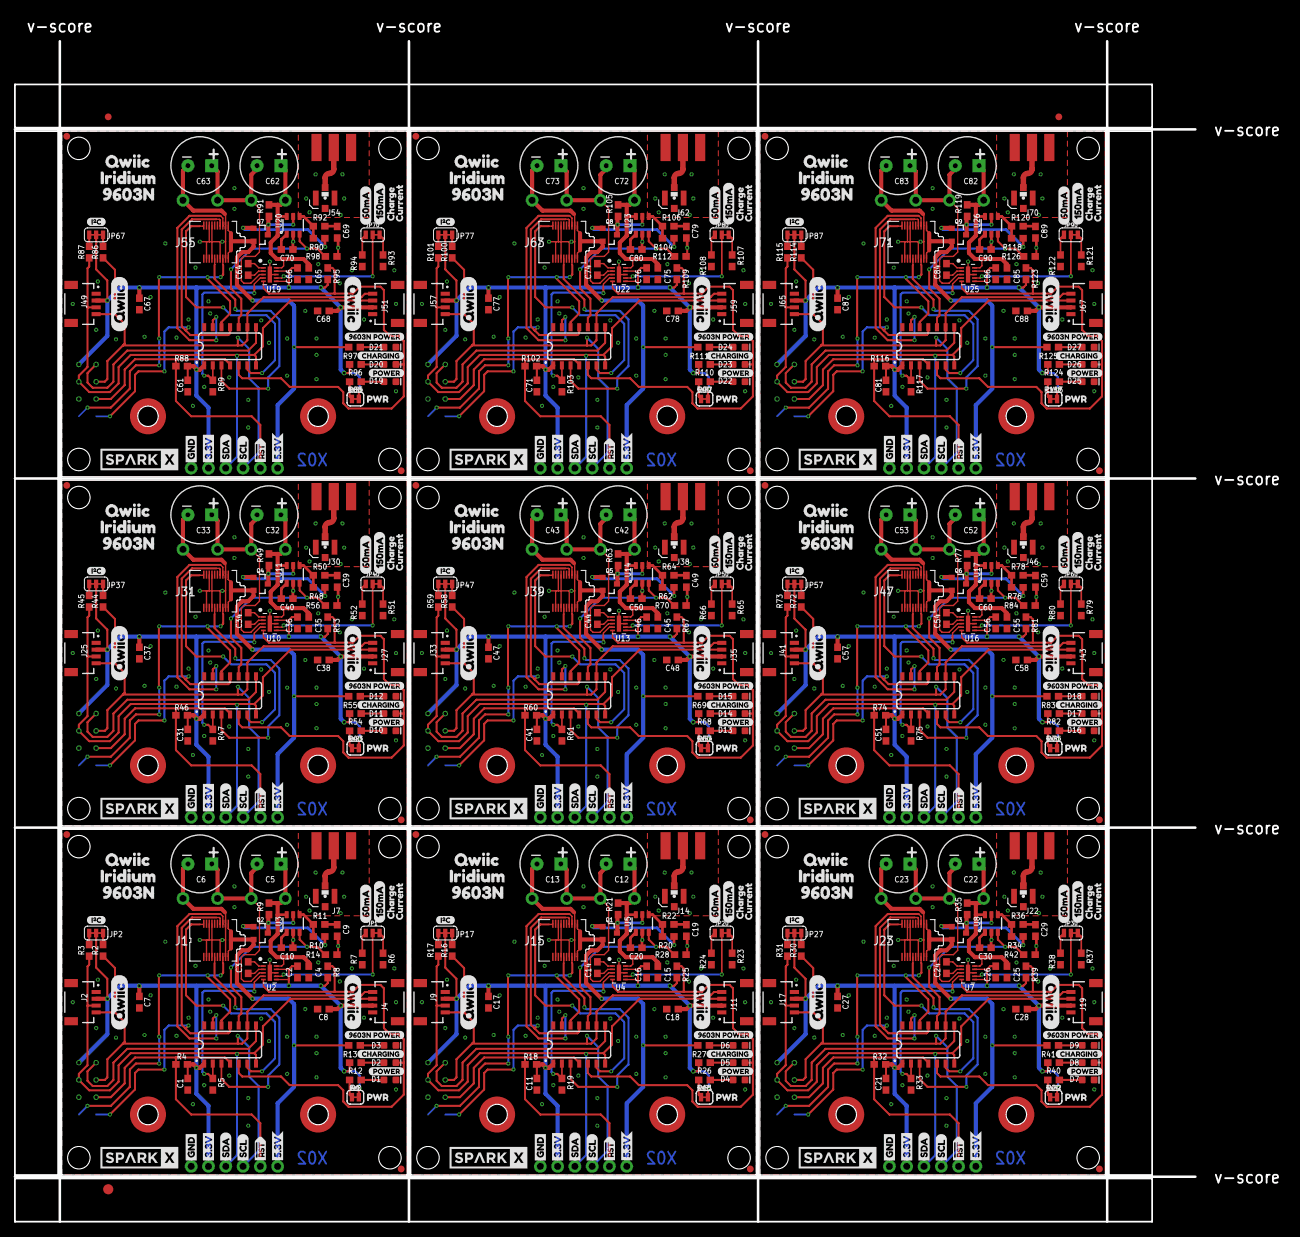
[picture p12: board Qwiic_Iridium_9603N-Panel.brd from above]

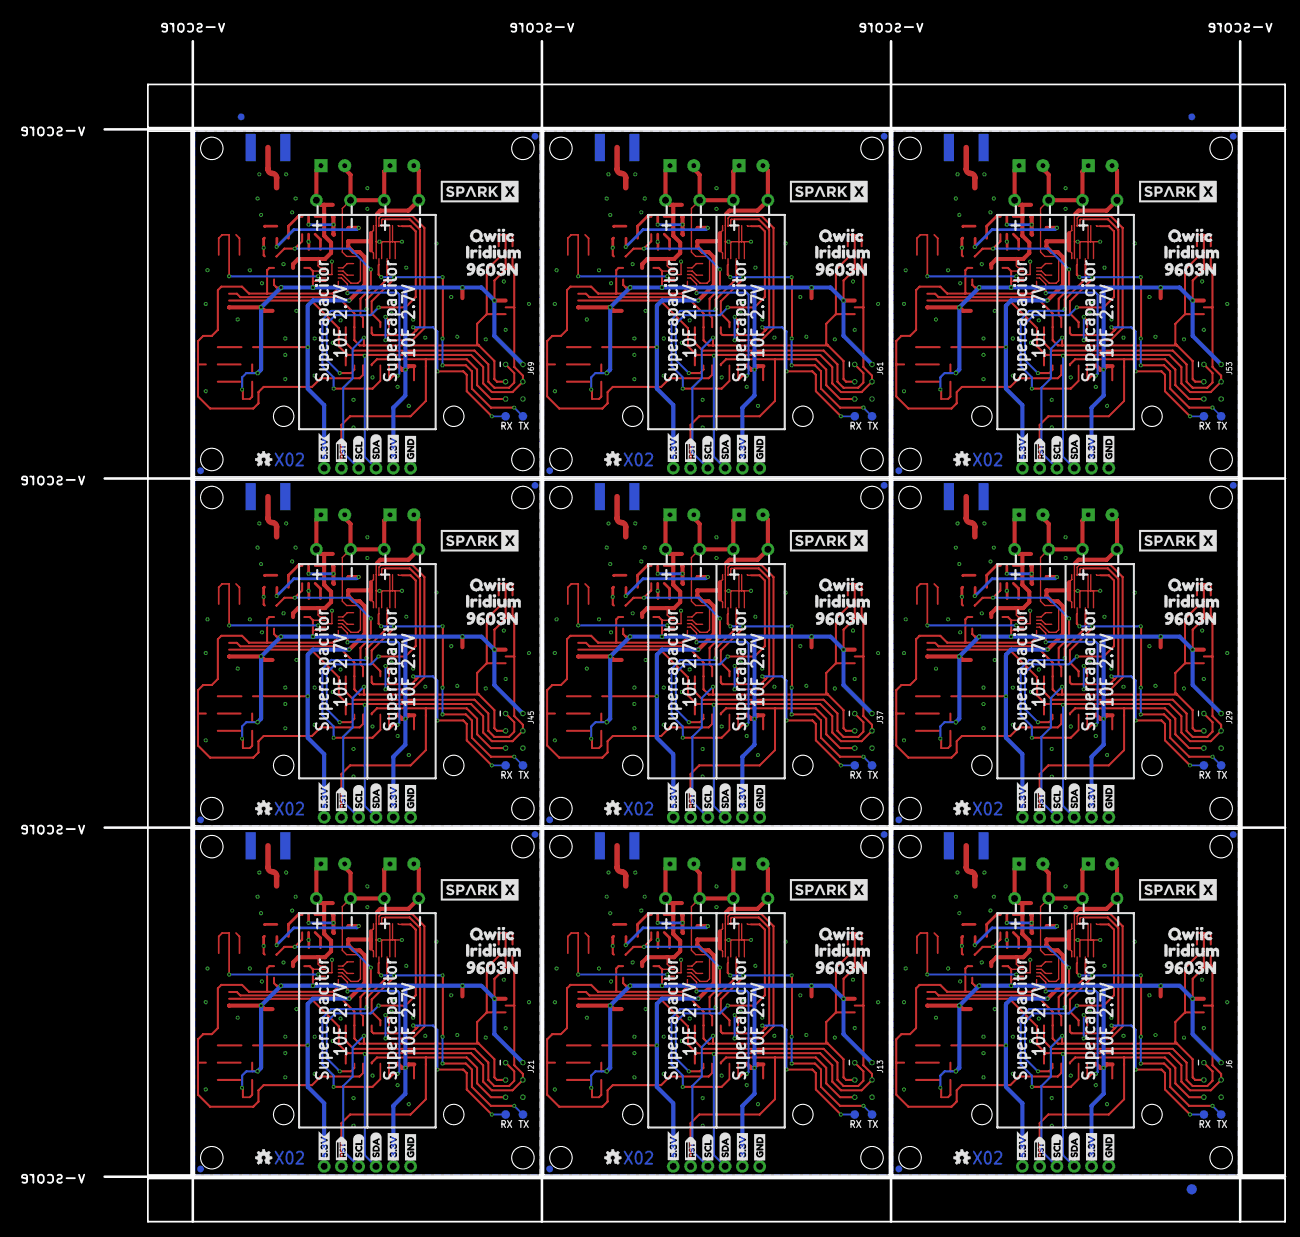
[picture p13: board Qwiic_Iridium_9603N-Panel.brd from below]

Board: 2 copper layers, 173.5 x 173.5 mm, 807 parts (147 on the bottom side), 306 nets.

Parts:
C1, C11, C21, C31, C41, C51, C61, C71, C81: 0.1uF; 0603
C2, C16, C26, C36, C46, C56, C66, C76, C86: 2.2uF; 0603
C3, C8, C10, C14, C18, C20, C24, C28, C30, C34, C38, C40, C44, C48, C50, C54, C58, C60, C64, C68, C70, C74, C78, C80, C84, C88, C90: 1.0uF; 0603
C4, C15, C25, C35, C45, C55, C65, C75, C85: 0.22uF; 0603
C5, C6, C12, C13, C22, C23, C32, C33, C42, C43, C52, C53, C62, C63, C72, C73, C82, C83: 1F 2.7V; CPOL-RADIAL-1F-2.7V
C7, C17, C27, C37, C47, C57, C67, C77, C87: 10uF; 0603
C9, C19, C29, C39, C49, C59, C69, C79, C89: 10nF; 0603
D1, D4, D7, D10, D13, D16, D19, D22, D25: RED; LED-0603
D2, D5, D8, D11, D14, D17, D20, D23, D26: Yellow; LED-0603
D3, D6, D9, D12, D15, D18, D21, D24, D27: GREEN; LED-0603
E1, E2, E3, E4, E5, E6, E7, E8, E9: ANTENNA-GROUNDEDEDGE_SMA; SMA-EDGE
E$1, E$2, E$3, E$4: FIDUCIAL-1X2
E$5, E$6: FIDUCIAL-1.5X3
J1, J15, J23, J31, J39, J47, J55, J63, J71: IRIDIUM_9603N
J2, J4, J9, J11, J17, J19, J25, J27, J33, J35, J41, J43, J49, J51, J57, J59, J65, J67: JST04_1MM_RA
J3, J10, J18, J26, J34, J42, J50, J58, J66: PTH; 1X04_NO_SILK
J5, J8, J12, J16, J20, J24, J28, J32, J36, J40, J44, J48, J52, J56, J60, J64, J68, J72: 1X01_NO_SILK
J6, J13, J21, J29, J37, J45, J53, J61, J69: ISP; 2X3_TEST_POINTS
J7, J14, J22, J30, J38, J46, J54, J62, J70: U.FL
JP1, JP20, JP30, JP40, JP50, JP60, JP70, JP80, JP90: JUMPER-SMT_3_1-NC_TRACE_SILK; SMT-JUMPER_3_1-NC_TRACE_SILK
JP2, JP17, JP27, JP37, JP47, JP57, JP67, JP77, JP87: JUMPER-SMT_3_2-NC_TRACE_SILK; SMT-JUMPER_3_2-NC_TRACE_SILK
JP3, JP4, JP9, JP10, JP11, JP12, JP18, JP19, JP21, JP22, JP28, JP29, JP31, JP32, JP38, JP39, JP41, JP42, JP48, JP49, JP51, JP52, JP58, JP59, JP61, JP62, JP68, JP69, JP71, JP72, JP78, JP79, JP81, JP82, JP88, JP89: STAND-OFF
JP5, JP6, JP7, JP8, JP13, JP14, JP15, JP16, JP23, JP24, JP25, JP26, JP33, JP34, JP35, JP36, JP43, JP44, JP45, JP46, JP53, JP54, JP55, JP56, JP63, JP64, JP65, JP66, JP73, JP74, JP75, JP76, JP83, JP84, JP85, JP86: FIDUCIAL1X2; FIDUCIAL-1X2
LOGO1, LOGO2, LOGO3, LOGO4, LOGO5, LOGO6, LOGO7, LOGO8, LOGO9: OSHW-LOGOMINI; OSHW-LOGO-MINI
PWR, PWR1, PWR2, PWR3, PWR4, PWR5, PWR6, PWR7, PWR8: JUMPER-SMT_2_NC_TRACE_SILK; SMT-JUMPER_2_NC_TRACE_SILK
Q1, Q2, Q3, Q4, Q5, Q6, Q7, Q8, Q9: 5.8A/30V/35mΩ; SOT23-3
R1, R12, R15, R26, R29, R40, R43, R54, R57, R68, R71, R82, R85, R96, R99, R110, R113, R124: 1k; 0603
R2, R3, R13, R16, R17, R27, R30, R31, R41, R44, R45, R55, R58, R59, R69, R72, R73, R83, R86, R87, R97, R100, R101, R111, R114, R115, R125: 2.2k; 0603
R4, R18, R32, R46, R60, R74, R88, R102, R116: 4.7k; 0603
R5, R14, R19, R28, R33, R42, R47, R56, R61, R70, R75, R84, R89, R98, R103, R112, R117, R126: 10k; 0603
R6, R23, R37, R51, R65, R79, R93, R107, R121: 12k; 0603
R7, R24, R38, R52, R66, R80, R94, R108, R122: 30.1k; 0603
R8, R25, R39, R53, R67, R81, R95, R109, R123: 100k; 0603
R9, R21, R35, R49, R63, R77, R91, R105, R119: 0.012 Ohm; 0603
R10, R11, R20, R22, R34, R36, R48, R50, R62, R64, R76, R78, R90, R92, R104, R106, R118, R120: 100; 0603
RX, RX1, RX2, RX3, RX4, RX5, RX6, RX7, RX8: TEST-POINT3X5; PAD.03X.05
SC1+, SC1+1, SC1+2, SC1+3, SC1+4, SC1+5, SC1+6, SC1+7, SC1+8, SC1-, SC1-1, SC1-2, SC1-3, SC1-4, SC1-5, SC1-6, SC1-7, SC1-8, SC2+, SC2+1, SC2+2, SC2+3, SC2+4, SC2+5, SC2+6, SC2+7, SC2+8, SC2-, SC2-1, SC2-2, SC2-3, SC2-4, SC2-5, SC2-6, SC2-7, SC2-8: 1X01_NO_SILK
TX, TX1, TX2, TX3, TX4, TX5, TX6, TX7, TX8: TEST-POINT3X5; PAD.03X.05
U1, U6, U9, U12, U15, U18, U21, U24, U27: ATTINY841SOIC; ATTINY841
U2, U4, U7, U10, U13, U16, U19, U22, U25: LTC3225EDDB#TRMPBF; DFN300X200-10L
U3, U5, U8, U11, U14, U17, U20, U23, U26: ADM4210-1; TSOT6
U$1, U$46, U$77, U$108, U$139, U$170, U$201, U$232, U$263: 60MA0
U$2, U$43, U$74, U$105, U$136, U$167, U$198, U$229, U$260: POWER0
U$3, U$22, U$33, U$36, U$64, U$67, U$95, U$98, U$126, U$129, U$157, U$160, U$188, U$191, U$219, U$222, U$250, U$253: GND1
U$4, U$21, U$28, U$37, U$63, U$68, U$94, U$99, U$125, U$130, U$156, U$161, U$187, U$192, U$218, U$223, U$249, U$254: 3#3V2
U$5, U$27, U$35, U$38, U$66, U$69, U$97, U$100, U$128, U$131, U$159, U$162, U$190, U$193, U$221, U$224, U$252, U$255: SDA8
U$6, U$26, U$34, U$39, U$65, U$70, U$96, U$101, U$127, U$132, U$158, U$163, U$189, U$194, U$220, U$225, U$251, U$256: SCL9
U$7, U$16, U$41, U$42, U$72, U$73, U$103, U$104, U$134, U$135, U$165, U$166, U$196, U$197, U$227, U$228, U$258, U$259: RST#-[>
U$8, U$40, U$71, U$102, U$133, U$164, U$195, U$226, U$257: I_SUPER2_C-()-03
U$9, U$44, U$75, U$106, U$137, U$168, U$199, U$230, U$261: CHARGING0
U$10, U$45, U$76, U$107, U$138, U$169, U$200, U$231, U$262: 9603N_POWER0
U$11, U$32, U$61, U$62, U$92, U$93, U$123, U$124, U$154, U$155, U$185, U$186, U$216, U$217, U$247, U$248, U$278, U$279: 5#3V0
U$12, U$17, U$23, U$25, U$50, U$51, U$56, U$57, U$81, U$82, U$87, U$88, U$112, U$113, U$118, U$119, U$143, U$144, U$149, U$150, U$174, U$175, U$180, U$181, U$205, U$206, U$211, U$212, U$236, U$237, U$242, U$243, U$267, U$268, U$273, U$274: QWIIC0
U$13, U$47, U$78, U$109, U$140, U$171, U$202, U$233, U$264: 150MA0
U$14, U$48, U$79, U$110, U$141, U$172, U$203, U$234, U$265: CHARGE0
U$15, U$49, U$80, U$111, U$142, U$173, U$204, U$235, U$266: CURRENT0
U$18, U$19, U$52, U$53, U$83, U$84, U$114, U$115, U$145, U$146, U$176, U$177, U$207, U$208, U$238, U$239, U$269, U$270: IRIDIUM0
U$20, U$24, U$54, U$55, U$85, U$86, U$116, U$117, U$147, U$148, U$178, U$179, U$209, U$210, U$240, U$241, U$271, U$272: 9603N0
U$29, U$30, U$58, U$59, U$89, U$90, U$120, U$121, U$151, U$152, U$182, U$183, U$213, U$214, U$244, U$245, U$275, U$276: SPARKX-LARGE
U$31, U$60, U$91, U$122, U$153, U$184, U$215, U$246, U$277: _PWR1

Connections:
3.3V: C1.1, C2.1, C7.1, C8.1, J2.2, J3.2, J4.2, J6.2, JP2.2, PWR.2, R4.2, R8.2, R12.2, U1.1, U2.6, U2.9
3.3V1: C11.1, C16.1, C17.1, C18.1, J9.2, J10.2, J11.2, J13.2, JP17.2, PWR1.2, R18.2, R25.2, R26.2, U4.6, U4.9, U6.1
3.3V2: C21.1, C26.1, C27.1, C28.1, J17.2, J18.2, J19.2, J21.2, JP27.2, PWR2.2, R32.2, R39.2, R40.2, U7.6, U7.9, U9.1
3.3V3: C31.1, C36.1, C37.1, C38.1, J25.2, J26.2, J27.2, J29.2, JP37.2, PWR3.2, R46.2, R53.2, R54.2, U10.6, U10.9, U12.1
3.3V4: C41.1, C46.1, C47.1, C48.1, J33.2, J34.2, J35.2, J37.2, JP47.2, PWR4.2, R60.2, R67.2, R68.2, U13.6, U13.9, U15.1
3.3V5: C51.1, C56.1, C57.1, C58.1, J41.2, J42.2, J43.2, J45.2, JP57.2, PWR5.2, R74.2, R81.2, R82.2, U16.6, U16.9, U18.1
3.3V6: C61.1, C66.1, C67.1, C68.1, J49.2, J50.2, J51.2, J53.2, JP67.2, PWR6.2, R88.2, R95.2, R96.2, U19.6, U19.9, U21.1
3.3V7: C71.1, C76.1, C77.1, C78.1, J57.2, J58.2, J59.2, J61.2, JP77.2, PWR7.2, R102.2, R109.2, R110.2, U22.6, U22.9, U24.1
3.3V8: C81.1, C86.1, C87.1, C88.1, J65.2, J66.2, J67.2, J69.2, JP87.2, PWR8.2, R116.2, R123.2, R124.2, U25.6, U25.9, U27.1
!RST: J5.1, J6.5, R4.1, U1.4
!RST1: J12.1, J13.5, R18.1, U6.4
!RST2: J20.1, J21.5, R32.1, U9.4
!RST3: J28.1, J29.5, R46.1, U12.4
!RST4: J36.1, J37.5, R60.1, U15.4
!RST5: J44.1, J45.5, R74.1, U18.4
!RST6: J52.1, J53.5, R88.1, U21.4
!RST7: J60.1, J61.5, R102.1, U24.4
!RST8: J68.1, J69.5, R116.1, U27.4
!SHDN: R5.2, U1.2, U2.4
!SHDN1: R19.2, U4.4, U6.2
!SHDN2: R33.2, U7.4, U9.2
!SHDN3: R47.2, U10.4, U12.2
!SHDN4: R61.2, U13.4, U15.2
!SHDN5: R75.2, U16.4, U18.2
!SHDN6: R89.2, U19.4, U21.2
!SHDN7: R103.2, U22.4, U24.2
!SHDN8: R117.2, U25.4, U27.2
EXT_PWR: J1.1, J1.2, J8.1, Q2.2, R13.2
EXT_PWR1: J15.1, J15.2, J16.1, Q1.2, R27.2
EXT_PWR2: J23.1, J23.2, J24.1, Q3.2, R41.2
EXT_PWR3: J31.1, J31.2, J32.1, Q4.2, R55.2
EXT_PWR4: J39.1, J39.2, J40.1, Q5.2, R69.2
EXT_PWR5: J47.1, J47.2, J48.1, Q6.2, R83.2
EXT_PWR6: J55.1, J55.2, J56.1, Q7.2, R97.2
EXT_PWR7: J63.1, J63.2, J64.1, Q8.2, R111.2
EXT_PWR8: J71.1, J71.2, J72.1, Q9.2, R125.2
GND: C1.2, C2.2, C4.2, C6.-, C7.2, C8.2, C9.2, C10.2, D1.C, D3.C, E1.GND@0, E1.GND@1, E1.GND@2, E1.GND@3, J1.3, J1.4, J1.8, J1.13, J1.14, J1.15, J1.18, J1.HOLE1, J1.HOLE2, J2.1, J3.1, J4.1, J6.6, J7.1, J7.2, R5.1, R6.1, R7.2, R14.2, SC2-.1, U1.14, U2.8, U2.11, U3.2
GND1: C11.2, C13.-, C15.2, C16.2, C17.2, C18.2, C19.2, C20.2, D4.C, D6.C, E2.GND@0, E2.GND@1, E2.GND@2, E2.GND@3, J9.1, J10.1, J11.1, J13.6, J14.1, J14.2, J15.3, J15.4, J15.8, J15.13, J15.14, J15.15, J15.18, J15.HOLE1, J15.HOLE2, R19.1, R23.1, R24.2, R28.2, SC2-1.1, U4.8, U4.11, U5.2, U6.14
GND2: C21.2, C23.-, C25.2, C26.2, C27.2, C28.2, C29.2, C30.2, D7.C, D9.C, E3.GND@0, E3.GND@1, E3.GND@2, E3.GND@3, J17.1, J18.1, J19.1, J21.6, J22.1, J22.2, J23.3, J23.4, J23.8, J23.13, J23.14, J23.15, J23.18, J23.HOLE1, J23.HOLE2, R33.1, R37.1, R38.2, R42.2, SC2-2.1, U7.8, U7.11, U8.2, U9.14
GND3: C31.2, C33.-, C35.2, C36.2, C37.2, C38.2, C39.2, C40.2, D10.C, D12.C, E4.GND@0, E4.GND@1, E4.GND@2, E4.GND@3, J25.1, J26.1, J27.1, J29.6, J30.1, J30.2, J31.3, J31.4, J31.8, J31.13, J31.14, J31.15, J31.18, J31.HOLE1, J31.HOLE2, R47.1, R51.1, R52.2, R56.2, SC2-3.1, U10.8, U10.11, U11.2, U12.14
GND4: C41.2, C43.-, C45.2, C46.2, C47.2, C48.2, C49.2, C50.2, D13.C, D15.C, E5.GND@0, E5.GND@1, E5.GND@2, E5.GND@3, J33.1, J34.1, J35.1, J37.6, J38.1, J38.2, J39.3, J39.4, J39.8, J39.13, J39.14, J39.15, J39.18, J39.HOLE1, J39.HOLE2, R61.1, R65.1, R66.2, R70.2, SC2-4.1, U13.8, U13.11, U14.2, U15.14
GND5: C51.2, C53.-, C55.2, C56.2, C57.2, C58.2, C59.2, C60.2, D16.C, D18.C, E6.GND@0, E6.GND@1, E6.GND@2, E6.GND@3, J41.1, J42.1, J43.1, J45.6, J46.1, J46.2, J47.3, J47.4, J47.8, J47.13, J47.14, J47.15, J47.18, J47.HOLE1, J47.HOLE2, R75.1, R79.1, R80.2, R84.2, SC2-5.1, U16.8, U16.11, U17.2, U18.14
GND6: C61.2, C63.-, C65.2, C66.2, C67.2, C68.2, C69.2, C70.2, D19.C, D21.C, E7.GND@0, E7.GND@1, E7.GND@2, E7.GND@3, J49.1, J50.1, J51.1, J53.6, J54.1, J54.2, J55.3, J55.4, J55.8, J55.13, J55.14, J55.15, J55.18, J55.HOLE1, J55.HOLE2, R89.1, R93.1, R94.2, R98.2, SC2-6.1, U19.8, U19.11, U20.2, U21.14
GND7: C71.2, C73.-, C75.2, C76.2, C77.2, C78.2, C79.2, C80.2, D22.C, D24.C, E8.GND@0, E8.GND@1, E8.GND@2, E8.GND@3, J57.1, J58.1, J59.1, J61.6, J62.1, J62.2, J63.3, J63.4, J63.8, J63.13, J63.14, J63.15, J63.18, J63.HOLE1, J63.HOLE2, R103.1, R107.1, R108.2, R112.2, SC2-7.1, U22.8, U22.11, U23.2, U24.14
GND8: C81.2, C83.-, C85.2, C86.2, C87.2, C88.2, C89.2, C90.2, D25.C, D27.C, E9.GND@0, E9.GND@1, E9.GND@2, E9.GND@3, J65.1, J66.1, J67.1, J69.6, J70.1, J70.2, J71.3, J71.4, J71.8, J71.13, J71.14, J71.15, J71.18, J71.HOLE1, J71.HOLE2, R117.1, R121.1, R122.2, R126.2, SC2-8.1, U25.8, U25.11, U26.2, U27.14
LTC3225_VOUT: C4.1, C5.+, R9.2, SC1+.1, U2.10, U3.6
LTC3225_VOUT1: C12.+, C15.1, R21.2, SC1+1.1, U4.10, U5.6
LTC3225_VOUT2: C22.+, C25.1, R35.2, SC1+2.1, U7.10, U8.6
LTC3225_VOUT3: C32.+, C35.1, R49.2, SC1+3.1, U10.10, U11.6
LTC3225_VOUT4: C42.+, C45.1, R63.2, SC1+4.1, U13.10, U14.6
LTC3225_VOUT5: C52.+, C55.1, R77.2, SC1+5.1, U16.10, U17.6
LTC3225_VOUT6: C62.+, C65.1, R91.2, SC1+6.1, U19.10, U20.6
LTC3225_VOUT7: C72.+, C75.1, R105.2, SC1+7.1, U22.10, U23.6
LTC3225_VOUT8: C82.+, C85.1, R119.2, SC1+8.1, U25.10, U26.6
MISO: J6.1, U1.8
MISO1: J13.1, U6.8
MISO2: J21.1, U9.8
MISO3: J29.1, U12.8
MISO4: J37.1, U15.8
MISO5: J45.1, U18.8
MISO6: J53.1, U21.8
MISO7: J61.1, U24.8
MISO8: J69.1, U27.8
unnamed: C5.-, C6.+, SC1-.1, SC2+.1, U2.3
unnamed: JP1.3, R6.2
unnamed: D1.A, R1.1
unnamed: JP1.1, R7.1
unnamed: D2.A, R12.1
unnamed: D3.A, R13.1
unnamed: E1.SIG, J7.FEED
unnamed: Q2.3, R9.1, U3.5
unnamed: C3.2, U2.2
unnamed: C3.1, U2.1
unnamed: JP1.2, U2.7
unnamed: Q2.1, R10.1
unnamed: R10.2, R11.1, U3.4
unnamed: C9.1, R11.2
unnamed: C10.1, U3.1
unnamed: PWR.1, R1.2
unnamed: D4.A, R15.1
unnamed: C14.2, U4.2
unnamed: C14.1, U4.1
unnamed: JP20.2, U4.7
unnamed: C12.-, C13.+, SC1-1.1, SC2+1.1, U4.3
unnamed: JP20.3, R23.2
unnamed: JP20.1, R24.1
unnamed: D5.A, R26.1
unnamed: D6.A, R27.1
unnamed: E2.SIG, J14.FEED
unnamed: Q1.3, R21.1, U5.5
unnamed: Q1.1, R20.1
unnamed: R20.2, R22.1, U5.4
unnamed: C19.1, R22.2
unnamed: C20.1, U5.1
unnamed: PWR1.1, R15.2
unnamed: D7.A, R29.1
unnamed: C24.2, U7.2
unnamed: C24.1, U7.1
unnamed: JP30.2, U7.7
unnamed: C22.-, C23.+, SC1-2.1, SC2+2.1, U7.3
unnamed: JP30.3, R37.2
unnamed: JP30.1, R38.1
unnamed: D8.A, R40.1
unnamed: D9.A, R41.1
unnamed: E3.SIG, J22.FEED
unnamed: Q3.3, R35.1, U8.5
unnamed: Q3.1, R34.1
unnamed: R34.2, R36.1, U8.4
unnamed: C29.1, R36.2
unnamed: C30.1, U8.1
unnamed: PWR2.1, R29.2
unnamed: D10.A, R43.1
unnamed: C34.2, U10.2
unnamed: C34.1, U10.1
unnamed: JP40.2, U10.7
unnamed: C32.-, C33.+, SC1-3.1, SC2+3.1, U10.3
unnamed: JP40.3, R51.2
unnamed: JP40.1, R52.1
unnamed: D11.A, R54.1
unnamed: D12.A, R55.1
unnamed: E4.SIG, J30.FEED
unnamed: Q4.3, R49.1, U11.5
unnamed: Q4.1, R48.1
unnamed: R48.2, R50.1, U11.4
unnamed: C39.1, R50.2
unnamed: C40.1, U11.1
unnamed: PWR3.1, R43.2
unnamed: D13.A, R57.1
unnamed: C44.2, U13.2
unnamed: C44.1, U13.1
unnamed: JP50.2, U13.7
unnamed: C42.-, C43.+, SC1-4.1, SC2+4.1, U13.3
unnamed: JP50.3, R65.2
unnamed: JP50.1, R66.1
unnamed: D14.A, R68.1
unnamed: D15.A, R69.1
unnamed: E5.SIG, J38.FEED
unnamed: Q5.3, R63.1, U14.5
unnamed: Q5.1, R62.1
unnamed: R62.2, R64.1, U14.4
unnamed: C49.1, R64.2
unnamed: C50.1, U14.1
unnamed: PWR4.1, R57.2
unnamed: D16.A, R71.1
unnamed: C54.2, U16.2
unnamed: C54.1, U16.1
unnamed: JP60.2, U16.7
unnamed: C52.-, C53.+, SC1-5.1, SC2+5.1, U16.3
unnamed: JP60.3, R79.2
unnamed: JP60.1, R80.1
unnamed: D17.A, R82.1
unnamed: D18.A, R83.1
unnamed: E6.SIG, J46.FEED
unnamed: Q6.3, R77.1, U17.5
unnamed: Q6.1, R76.1
unnamed: R76.2, R78.1, U17.4
unnamed: C59.1, R78.2
unnamed: C60.1, U17.1
unnamed: PWR5.1, R71.2
unnamed: D19.A, R85.1
unnamed: C64.2, U19.2
unnamed: C64.1, U19.1
unnamed: JP70.2, U19.7
unnamed: C62.-, C63.+, SC1-6.1, SC2+6.1, U19.3
unnamed: JP70.3, R93.2
unnamed: JP70.1, R94.1
unnamed: D20.A, R96.1
unnamed: D21.A, R97.1
unnamed: E7.SIG, J54.FEED
unnamed: Q7.3, R91.1, U20.5
unnamed: Q7.1, R90.1
unnamed: R90.2, R92.1, U20.4
unnamed: C69.1, R92.2
unnamed: C70.1, U20.1
unnamed: PWR6.1, R85.2
unnamed: D22.A, R99.1
unnamed: C74.2, U22.2
unnamed: C74.1, U22.1
unnamed: JP80.2, U22.7
unnamed: C72.-, C73.+, SC1-7.1, SC2+7.1, U22.3
unnamed: JP80.3, R107.2
unnamed: JP80.1, R108.1
unnamed: D23.A, R110.1
unnamed: D24.A, R111.1
unnamed: E8.SIG, J62.FEED
unnamed: Q8.3, R105.1, U23.5
unnamed: Q8.1, R104.1
unnamed: R104.2, R106.1, U23.4
unnamed: C79.1, R106.2
unnamed: C80.1, U23.1
unnamed: PWR7.1, R99.2
unnamed: D25.A, R113.1
unnamed: C84.2, U25.2
unnamed: C84.1, U25.1
unnamed: JP90.2, U25.7
unnamed: C82.-, C83.+, SC1-8.1, SC2+8.1, U25.3
unnamed: JP90.3, R121.2
unnamed: JP90.1, R122.1
unnamed: D26.A, R124.1
unnamed: D27.A, R125.1
unnamed: E9.SIG, J70.FEED
unnamed: Q9.3, R119.1, U26.5
unnamed: Q9.1, R118.1
unnamed: R118.2, R120.1, U26.4
unnamed: C89.1, R120.2
unnamed: C90.1, U26.1
unnamed: PWR8.1, R113.2
NA: J1.19, U1.6
NA1: J15.19, U6.6
NA2: J23.19, U9.6
NA3: J31.19, U12.6
NA4: J39.19, U15.6
NA5: J47.19, U18.6
NA6: J55.19, U21.6
NA7: J63.19, U24.6
NA8: J71.19, U27.6
ON_OFF: J1.5, U1.13
ON_OFF1: J15.5, U6.13
ON_OFF2: J23.5, U9.13
ON_OFF3: J31.5, U12.13
ON_OFF4: J39.5, U15.13
ON_OFF5: J47.5, U18.13
ON_OFF6: J55.5, U21.13
ON_OFF7: J63.5, U24.13
ON_OFF8: J71.5, U27.13
PGOOD: D2.C, R8.1, U1.5, U2.5
PGOOD1: D5.C, R25.1, U4.5, U6.5
PGOOD2: D8.C, R39.1, U7.5, U9.5
PGOOD3: D11.C, R53.1, U10.5, U12.5
PGOOD4: D14.C, R67.1, U13.5, U15.5
PGOOD5: D17.C, R81.1, U16.5, U18.5
PGOOD6: D20.C, R95.1, U19.5, U21.5
PGOOD7: D23.C, R109.1, U22.5, U24.5
PGOOD8: D26.C, R123.1, U25.5, U27.5
PWR_EN: R14.1, U1.10, U3.3
PWR_EN1: R28.1, U5.3, U6.10
PWR_EN2: R42.1, U8.3, U9.10
PWR_EN3: R56.1, U11.3, U12.10
PWR_EN4: R70.1, U14.3, U15.10
PWR_EN5: R84.1, U17.3, U18.10
PWR_EN6: R98.1, U20.3, U21.10
PWR_EN7: R112.1, U23.3, U24.10
PWR_EN8: R126.1, U26.3, U27.10
RI: J1.12, U1.3
RI1: J15.12, U6.3
RI2: J23.12, U9.3
RI3: J31.12, U12.3
RI4: J39.12, U15.3
RI5: J47.12, U18.3
RI6: J55.12, U21.3
RI7: J63.12, U24.3
RI8: J71.12, U27.3
RX(OUT): J1.7, RX.P$1, U1.11
RX(OUT)1: J15.7, RX1.P$1, U6.11
RX(OUT)2: J23.7, RX2.P$1, U9.11
RX(OUT)3: J31.7, RX3.P$1, U12.11
RX(OUT)4: J39.7, RX4.P$1, U15.11
RX(OUT)5: J47.7, RX5.P$1, U18.11
RX(OUT)6: J55.7, RX6.P$1, U21.11
RX(OUT)7: J63.7, RX7.P$1, U24.11
RX(OUT)8: J71.7, RX8.P$1, U27.11
SCL: J2.4, J3.4, J4.4, J6.3, R2.1, U1.9
SCL1: J9.4, J10.4, J11.4, J13.3, R16.1, U6.9
SCL2: J17.4, J18.4, J19.4, J21.3, R30.1, U9.9
SCL3: J25.4, J26.4, J27.4, J29.3, R44.1, U12.9
SCL4: J33.4, J34.4, J35.4, J37.3, R58.1, U15.9
SCL5: J41.4, J42.4, J43.4, J45.3, R72.1, U18.9
SCL6: J49.4, J50.4, J51.4, J53.3, R86.1, U21.9
SCL7: J57.4, J58.4, J59.4, J61.3, R100.1, U24.9
SCL8: J65.4, J66.4, J67.4, J69.3, R114.1, U27.9
SCL_PU1: JP2.1, R2.2
SCL_PU2: JP17.1, R16.2
SCL_PU3: JP27.1, R30.2
SCL_PU4: JP37.1, R44.2
SCL_PU5: JP47.1, R58.2
SCL_PU6: JP57.1, R72.2
SCL_PU7: JP67.1, R86.2
SCL_PU8: JP77.1, R100.2
SCL_PU9: JP87.1, R114.2
SDA: J2.3, J3.3, J4.3, J6.4, R3.1, U1.7
SDA1: J9.3, J10.3, J11.3, J13.4, R17.1, U6.7
SDA2: J17.3, J18.3, J19.3, J21.4, R31.1, U9.7
SDA3: J25.3, J26.3, J27.3, J29.4, R45.1, U12.7
SDA4: J33.3, J34.3, J35.3, J37.4, R59.1, U15.7
SDA5: J41.3, J42.3, J43.3, J45.4, R73.1, U18.7
SDA6: J49.3, J50.3, J51.3, J53.4, R87.1, U21.7
SDA7: J57.3, J58.3, J59.3, J61.4, R101.1, U24.7
SDA8: J65.3, J66.3, J67.3, J69.4, R115.1, U27.7
SDA_PU1: JP2.3, R3.2
SDA_PU2: JP17.3, R17.2
SDA_PU3: JP27.3, R31.2
SDA_PU4: JP37.3, R45.2
SDA_PU5: JP47.3, R59.2
SDA_PU6: JP57.3, R73.2
SDA_PU7: JP67.3, R87.2
SDA_PU8: JP77.3, R101.2
SDA_PU9: JP87.3, R115.2
TX(IN): J1.6, TX.P$1, U1.12
TX(IN)1: J15.6, TX1.P$1, U6.12
TX(IN)2: J23.6, TX2.P$1, U9.12
TX(IN)3: J31.6, TX3.P$1, U12.12
TX(IN)4: J39.6, TX4.P$1, U15.12
TX(IN)5: J47.6, TX5.P$1, U18.12
TX(IN)6: J55.6, TX6.P$1, U21.12
TX(IN)7: J63.6, TX7.P$1, U24.12
TX(IN)8: J71.6, TX8.P$1, U27.12

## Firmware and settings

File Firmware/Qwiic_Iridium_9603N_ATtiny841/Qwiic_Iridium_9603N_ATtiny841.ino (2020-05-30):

/*
  Qwiic Iridium 9603N
  By: Paul Clark
  Date: 21st September 2019
  Version: 1.1

  Change Log:

  V1.1 21st September 2019
  Added the low power mode (requested by Adam Garbo): bit 6 of the IO Register indicates if the 841 should enter
  low power mode after sleep_after millis of inactivity. Set bit 6 high to enable the low power mode.

  V1.0 11th August 2019:
  First commit
  
  Based extensively on:
  Qwiic MP3 Trigger (April 23rd, 2018) and the SparkFun Ublox library
  By: Nathan Seidle, SparkFun Electronics
  
  License: This code is public domain but you buy me a beer if you use this and we meet someday (Beerware license).

  goToSleep adapted from Jack Christensen's AVR Sleep example for the ATtinyX4:
  https://gist.github.com/JChristensen/5616922

  Uses Spence Konde's ATTinyCore boards:
  https://github.com/SpenceKonde/ATTinyCore
  https://github.com/SpenceKonde/ATTinyCore/blob/master/Installation.md
  Add this URL to the Additional Boards Manager URLs in File\Preferences:
  http://drazzy.com/package_drazzy.com_index.json
  and then use the Boards Manager to add support for the ATtiny

  Set Board to ATtiny441/841 (No bootloader)
  Set Chip to ATtiny841
  Set Clock to 8MHz(internal)
  Set BOD Level to BOD Enabled 1.8V
  Set BOD Mode (Active) and (Sleep) to BOD Disabled (this helps reduce power consumption in low power mode)
  Set Save EEPROM to EEPROM Not Retained
  * Set Pin Mapping to Clockwise *
  * Set Wire Modes to Slave Only *
  Set millis()/micros():"Enabled" to Enabled

  If you are using AVRDUDESS to program the ATtiny841, set the Fuses to:
  L: 0xE2 (CKDIV8 disabled, CKOUT disabled, SUT slowly rising, CKSEL internal 8MHz)
  H: 0xDF (RSTDISBL not disabled, DWEN not enabled, SPIEN enabled, WDTON not always on, EESAVE EEPROM not retained, BOD disabled)
  E: 0xFF (SELFPRGEN disabled)

  Pin Allocation:
  0:  Physical Pin 13 (PA0)           : 9603N ON_OFF - pull high to enable the 9603N, pull low to disable it
  1:  Physical Pin 12 (PA1 / TXD0)    : Serial TXD0 - connected to 9603N TX(IN)
  2:  Physical Pin 11 (PA2 / RXD0)    : Serial RXD0 - connected to 9603N RX(OUT)
  3:  Physical Pin 10 (PA3)           : PWR_EN - pull high to enable the 5.3V supply to the 9603N via the P-FET
  4:  Physical Pin 9  (PA4 / SCL/SCK) : I2C SCL
  5:  Physical Pin 8  (PA5 / MISO)    : MISO - connected to pin 1 of the ISP header
  6:  Physical Pin 7  (PA6 / MOSI/SDA): I2C SDA
  7:  Physical Pin 6  (PA7)           : 9603N Network Available - high when the 9603 can successfully receive the Ring Channel
  8:  Physical Pin 5  (PB2)           : LTC3225 Power Good - goes high when the supercapacitors are charged (will also be high when !SHDN is low!)
  9:  Physical Pin 3  (PB1 / INT0)    : 9603N Ring Indicator - will pulse low twice when a new Mobile Terminated SBD message is available
  10: Physical Pin 2  (PB0)           : LTC3225 !SHDN - pull low to disable the supercapacitor charger
  11: Physical Pin 4  (!RESET / PB3)  : ATtiny841 !Reset

  The ATtiny's I2C address is 0x63

  The I2C 'registers' are:
  IO_REG: 0x10 (the I/O pin register)
  LEN_REG: 0xFD (the serial length register: 2 bytes (MSB, LSB) indicating how many serial characters are available to be read)
  DATA_REG: 0xFF (the serial data register: used to read and write serial data from/to the 9603N)

  To read the I/O pins, the Master should: beginTransmission(0x63); write(0x10); endTransmission(false); requestFrom(0x63, 1);

  To write to the I/O pins, the Master should: beginTransmission(0x63); write(0x10); write(<new_output_pin_configuration>); endTransmission(); 
  
  Use a read-modify-write approach when setting output pin(s).

  To write serial data to the 9603N, the Master should: beginTransmission(0x63); write(0xFF); write each byte; endTransmission();

  If there are more than 32 bytes to be written, multiple cycles should be used using endTransmission(false) so the bus is not released part way through.

  To read serial data from the 9603N, the Master should: beginTransmission(0x63); write(0xFD); endTransmission(false); requestFrom(0x63, 2);
  
  The two bytes returned by the requestFrom will be the number of bytes waiting in the serial buffer in MSB, LSB format

  The Master should then request _all_ the serial data (up to) SER_PACKET_SIZE (default 8) bytes at a time from the DATA_REG 'register' 0xFF.
  E.g. if there are 13 bytes waiting to be read, the Master should:

  beginTransmission(0x63); write(0xFF); endTransmission(false);
  requestFrom(0x63, 8, false);
  requestFrom(0x63, 5);

  (This is because the requestEvent does not know how many bytes have been requested!)

  The Ring Indicator bit in the IO_REGISTER is a flag set by the RI signal via INT0.
  To clear the flag: read the I/O pins; clear the IO_RI bit; write the new pin configuration.

*/

#include <Wire.h>

#include <avr/sleep.h> //Needed for sleep_mode
//#include <avr/power.h> //Needed for powering down perihperals such as the ADC/TWI and Timers

//Define the ATtiny841's I2C address
const uint8_t I2C_ADDRESS = 0x63;

//Define the I2C 'registers'
#define IO_REG 0x10 // Read/write the I/O pins
#define LEN_REG 0xFD // The number of serial bytes waiting to be read (MSB, LSB)
#define DATA_REG 0xFF // The serial data 'register'

volatile uint8_t last_address = 0; // Last receiveEvent 'address', used to define what to send during a requestEvent
volatile uint8_t serAvailLSB = 0; // Stored LSB of serial available
volatile uint8_t serAvailMSB = 0; // Stored MSB of serial available

#define SER_PACKET_SIZE 8 // Return up to this many bytes when reading serial data from the DATA_REG

//These are the bit definitions for the IO 'register'
const uint8_t IO_SHDN    = (1 << 0); // LTC3225 !SHDN : Read / Write
const uint8_t IO_PWR_EN  = (1 << 1); // 9603N power enable via the P-FET : Read / Write
const uint8_t IO_ON_OFF  = (1 << 2); // 9603N ON_OFF pin : Read / Write
const uint8_t IO_RI      = (1 << 3); // 9603N Ring Indicator _flag_ : Read / Write (Set by the INT0 service routine, _cleared_ by writing a _1_ to this bit)
const uint8_t IO_NA      = (1 << 4); // 9603N Network Available : Read only
const uint8_t IO_PGOOD   = (1 << 5); // LTC3225 PGOOD : Read only
const uint8_t IO_LOW_PWR = (1 << 6); // Low Power Mode : Read / Write : Set this bit to enable low power mode

//Low Power Settings
const unsigned long sleep_after = 1000; // Engage low power mode after this many millis (if low power mode is enabled)
volatile unsigned long last_activity; // Used to store the value of millis when the last I2C activity took place
volatile boolean LOW_POWER_MODE = false; // Indicates if low power mode is in use

//Create the IO 'register'
//A '1' in any of the bits indicates that the pin is ON (not necessarily that it is HIGH!)
volatile byte IO_REGISTER;

//Create a flag for the RI (INT0) interrupt and clear it
volatile boolean RI_FLAG = false;

//Digital pins
const byte ON_OFF = 0; // 9603N ON_OFF - pull high to enable the 9603N, pull low to disable it
const byte TXPIN = 1; // Serial Tx pin
const byte RXPIN = 2; // Serial Rx pin
const byte PWR_EN = 3; // PWR_EN - pull high to enable the 5.3V supply to the 9603N via the P-FET
const byte NA = 7; // 9603N Network Available - high when the 9603 can successfully receive the Ring Channel
const byte PGOOD = 8; // LTC3225 Power Good - goes high when the supercapacitors are charged (will also be high when !SHDN is low!)
const byte RI = 9; // 9603N Ring Indicator - will pulse low twice when a new Mobile Terminated SBD message is available
const byte SHDN = 10; // LTC3225 !SHDN - pull high to enable the supercapacitor charger

//Define the ON and OFF states for each pin
#define ON_OFF__ON  HIGH // 9603N ON_OFF - pull high to enable the 9603N, pull low to disable it
#define ON_OFF__OFF LOW
#define PWR_EN__ON  HIGH // PWR_EN - pull high to enable the 5.3V supply to the 9603N via the P-FET
#define PWR_EN__OFF LOW
#define SHDN__ON    HIGH // LTC3225 !SHDN - pull high to enable the supercapacitor charger
#define SHDN__OFF   LOW
#define NA__ON      HIGH // 9603N Network Available - high when the 9603 can successfully receive the Ring Channel
#define NA__OFF     LOW
#define PGOOD__ON   HIGH // LTC3225 Power Good - goes high when the supercapacitors are charged (will also be high when !SHDN is low!)
#define PGOOD__OFF  LOW

//INT0 Interrupt Service Routine
//Called on the FALLING edge of the RI pin
void int0ISR() { RI_FLAG = true; } // Set RI_FLAG to true

void setup()
{
  // Digital outputs
  pinMode(ON_OFF, OUTPUT);
  digitalWrite(ON_OFF, ON_OFF__OFF); // Disable the 9603N until PGOOD has gone high
  pinMode(PWR_EN, OUTPUT);
  digitalWrite(PWR_EN, PWR_EN__OFF); // Disable power to the 9603N until PGOOD has gone high
  pinMode(SHDN, OUTPUT);
  digitalWrite(SHDN, SHDN__OFF); // Disable the LTC3225 supercapacitor charger

  // Initialize the IO_REGISTER
  IO_REGISTER = 0; // Clear the IO register

  // Digital inputs
  pinMode(PGOOD, INPUT); // Has its own pullup
  pinMode(NA, INPUT);
  pinMode(RI, INPUT);

  // Serial pins for software serial
  pinMode(TXPIN, OUTPUT); // Tx pin
  pinMode(RXPIN, INPUT); // Rx pin

  // Enable RI interrupts
  attachInterrupt(0, int0ISR, FALLING); // Attach the INT0 interrupt, falling edge (ATTinyCore requires the pin number to be 0)

  // Open serial communication with the 9603N
  Serial.begin(19200); //9603N communicates at 19200bps

  //Begin listening on I2C
  startI2C();

  //Initialise last_activity
  last_activity = millis();
}

void loop()
{
  if (LOW_POWER_MODE) // Is low power mode enabled?
  {
    // If low power mode is enabled, put the 841 into power-down mode after sleep_after millis of inactivity
    if (millis() > (last_activity + sleep_after)) // Have we reached the inactivity limit?
    {
      goToSleep(); // Put the 841 into power-down mode
      // ZZZzzz...
      last_activity = millis(); // After waking, update last_activity so we stay awake for at least sleep_after millis
    }
  }
  noIntDelay(1); // Delay for 1msec to avoid thrashing millis()
}

//Begin listening on I2C bus as I2C slave using the global I2C_ADDRESS
void startI2C()
{
//  Wire.end(); //Before we can change addresses we need to stop

  Wire.begin(I2C_ADDRESS); //Do the Wire.begin using the defined I2C_ADDRESS

  //The connections to the interrupts are severed when a Wire.begin occurs. So re-declare them.
  Wire.onReceive(receiveEvent);
  Wire.onRequest(requestEvent);
}

//goToSleep adapted from: https://gist.github.com/JChristensen/5616922
//Hardwired for the ATtiny441/841 (may not work on other ATtiny's)
//Brown Out Detection is disabled via the fuse bits:
//Set BOD Mode (Active) and (Sleep) to BOD Disabled in the board settings.
void goToSleep(void)
{
    byte adcsra = ADCSRA; //save ADCSRA (ADC control and status register A)
    ADCSRA &= ~_BV(ADEN); //disable ADC by clearing the ADEN bit
    
    byte acsr0a = ACSR0A; //save ACSR0A (Analog Comparator 0 control and status register)
    ACSR0A &= ~_BV(ACIE0); //disable AC0 interrupt
    ACSR0A |= _BV(ACD0); //disable ACO by setting the ACD0 bit
    
    byte acsr1a = ACSR1A; //save ACSR1A (Analog Comparator 1 control and status register)
    ACSR1A &= ~_BV(ACIE1); //disable AC1 interrupt
    ACSR1A |= _BV(ACD1); //disable AC1 by setting the ACD1 bit
    
    byte prr = PRR; // Save the power reduction register
    // Disable the ADC, USART1, SPI, Timer1 and Timer2
    // (Leave TWI, USART0 and Timer0 enabled)
    PRR |= _BV(PRADC) | _BV(PRUSART1) | _BV(PRSPI) | _BV(PRTIM1) | _BV(PRTIM2); 
    
    byte mcucr = MCUCR; // Save the MCU Control Register
    // Set Sleep Enable (SE=1), Power-down Sleep Mode (SM1=1, SM0=0), INT0 Falling Edge (ISC01=1, ISC00=0)
    MCUCR = _BV(SE) | _BV(SM1) | _BV(ISC01);

    sleep_cpu(); //go to sleep
    
    MCUCR = mcucr; // Restore the MCU control register
    PRR = prr; // Restore the power reduction register
    ACSR1A = acsr1a; // Restore ACSR1A    
    ACSR0A = acsr0a; // Restore ACSR0A    
    ADCSRA = adcsra; //Restore ADCSRA
}

//Software delay. Does not rely on internal timers.
void noIntDelay(byte amount)
{
  for (volatile byte y = 0 ; y < amount ; y++)
  {
    //ATtiny84 at 8MHz
    for (volatile unsigned int x = 0 ; x < 350 ; x++) //1ms at 8MHz
    {
      __asm__("nop\n\t");
    }
  }
}

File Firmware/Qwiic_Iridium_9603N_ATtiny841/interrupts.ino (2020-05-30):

// Qwiic Iridium 9603N interrupt routines

// I2C receiveEvent
// ================
// Handle a write to the IO pins or the Serial port
// If the first byte is IO_REG (0x10), read one more byte if present and write the contents to the IO pins.
// If the first byte is LEN_REG (0xFD), store it in last_address so we know what to do during the next requestEvent
// If the first byte is DATA_REG (0xFF), keep reading bytes (if any) and write them to the 9603 serial port.
void receiveEvent(int numberOfBytesReceived) {
  if (numberOfBytesReceived > 0) { // Check that we received some data (!) (hopefully redundant!)
    
    uint8_t incoming = Wire.read(); // Read the first byte
    last_address = incoming; // Store this byte in last_address so we know what to do during the next requestEvent

    if (incoming == IO_REG) { // Does the Master want to read or set the I/O pins?
      if (numberOfBytesReceived > 1) { // Did the Master send a second byte to set the I/O pins?
        uint8_t incoming2 = Wire.read(); // Read the second byte

        if (incoming2 & IO_SHDN) { // If the SHDN bit is ON
          digitalWrite(SHDN, SHDN__ON); // Turn the pin ON
        }
        else {
          digitalWrite(SHDN, SHDN__OFF); // Turn the pin OFF
        }
        
        if (incoming2 & IO_PWR_EN) { // If the PWR_EN bit is ON
          digitalWrite(PWR_EN, PWR_EN__ON); // Turn the pin ON
        }
        else {
          digitalWrite(PWR_EN, PWR_EN__OFF); // Turn the pin OFF
        }
        
        if (incoming2 & IO_ON_OFF) { // If the ON_OFF bit is ON
          digitalWrite(ON_OFF, ON_OFF__ON); // Turn the pin ON
        }
        else {
          digitalWrite(ON_OFF, ON_OFF__OFF); // Turn the pin OFF
        }
        
        if ((incoming2 & IO_RI) == 0x00) { // If the RI bit is clear
          RI_FLAG = false; // Clear the RI flag
        }
        
        LOW_POWER_MODE = ((incoming2 & IO_LOW_PWR) == IO_LOW_PWR); // Update low power mode
      }
      if (numberOfBytesReceived > 2) // Did we receive any unexpected extra data?
      {
        for (int i = 2; i < numberOfBytesReceived; i++) // If we did, mop up the extra bytes - hopefully redundant?!
        {
          Wire.read();
        }
      }
    }

    else if (incoming == DATA_REG) { // Does the Master want to write serial data to the 9603N?
      if (numberOfBytesReceived > 1) // If the Master sent any serial data, write it to the 9603 now
      {
        for (int i = 1; i < numberOfBytesReceived; i++)
        {
          uint8_t incoming2 = Wire.read();
          Serial.write(incoming2);
        }
      }
    }

    else if (incoming == LEN_REG) { // Does the Master want to read the available serial length?
      // We shouldn't need to do anything (except update last_address)
      if (numberOfBytesReceived > 1) // Did we receive any unexpected extra data?
      {
        for (int i = 1; i < numberOfBytesReceived; i++) // If we did, mop up the extra bytes - hopefully redundant?!
        {
          Wire.read();
        }
      }
    }
  }
  
  last_activity = millis(); // Update last_activity
}

// I2C requestEvent
// ================
// Handle a read of the IO pins or the Serial port
// If last_address was IO_REG (0x10) then return the status of the IO pins
// If last_address was LEN_REG (0xFD), return the MSB and LSB of the serial buffer length and store them in serAvailMSB/LSB
// If last_address was DATA_REG (0xFF), return up to SER_PACKET_SIZE bytes from the serial buffer and update serAvailMSB/LSB
void requestEvent()
{
  if (last_address == IO_REG) // Return the status of the IO pins
  {
    // Read the IO pins one at a time and set or clear bits in IO_REGISTER appropriately
    
    if (digitalRead(SHDN) == SHDN__ON) { // If the SHDN pin is in its ON state (not necessarily that it is HIGH)
      IO_REGISTER |= IO_SHDN; // Set the SHDN bit in IO_REGISTER
    }
    else {
      IO_REGISTER &= ~IO_SHDN; // Clear the SHDN bit in IO_REGISTER
    }
    
    if (digitalRead(PWR_EN) == PWR_EN__ON) { // If the PWR_EN pin is in its ON state (not necessarily that it is HIGH)
      IO_REGISTER |= IO_PWR_EN; // Set the PWR_EN bit in IO_REGISTER
    }
    else {
      IO_REGISTER &= ~IO_PWR_EN; // Clear the PWR_EN bit in IO_REGISTER
    }
    
    if (digitalRead(ON_OFF) == ON_OFF__ON) { // If the ON_OFF pin is in its ON state (not necessarily that it is HIGH)
      IO_REGISTER |= IO_ON_OFF; // Set the ON_OFF bit in IO_REGISTER
    }
    else {
      IO_REGISTER &= ~IO_ON_OFF; // Clear the ON_OFF bit in IO_REGISTER
    }
    
    if (RI_FLAG == true) { // If the RI_FLAG is true (set by the ISR)
      IO_REGISTER |= IO_RI; // Set the RI bit in IO_REGISTER
    }
    else {
      IO_REGISTER &= ~IO_RI; // Clear the RI bit in IO_REGISTER
    }
    
    if (digitalRead(NA) == NA__ON) { // If the NA pin is in its ON state (not necessarily that it is HIGH)
      IO_REGISTER |= IO_NA; // Set the NA bit in IO_REGISTER
    }
    else {
      IO_REGISTER &= ~IO_NA; // Clear the NA bit in IO_REGISTER
    }
    
    if (digitalRead(PGOOD) == PGOOD__ON) { // If the PGOOD pin is in its ON state (not necessarily that it is HIGH)
      IO_REGISTER |= IO_PGOOD; // Set the PGOOD bit in IO_REGISTER
    }
    else {
      IO_REGISTER &= ~IO_PGOOD; // Clear the PGOOD bit in IO_REGISTER
    }
  
    if (LOW_POWER_MODE) { // If low power mode is enabled
      IO_REGISTER |= IO_LOW_PWR; // Set the low power bit in IO_REGISTER
    }
    else {
      IO_REGISTER &= ~IO_LOW_PWR; // Clear the low power bit in IO_REGISTER
    }
  
    // Now write IO_REGISTER to I2C
    Wire.write(IO_REGISTER);

    // Reset last_address to zero
    last_address = 0;
  }

  else if (last_address == LEN_REG) // Return the MSB and LSB of the serial buffer length and store them in serAvailMSB/LSB
  {
    //Check how many bytes are available in the serial buffer
    uint16_t avail = Serial.available();
    
    //Store the MSB for the subsequent requestEvent
    serAvailMSB = (uint8_t)((avail & 0xFF00) >> 8);
    
    //Store the LSB for the subsequent  requestEvent
    serAvailLSB = (uint8_t)(avail & 0xFF);

    uint8_t buff[2];
    buff[0] = serAvailMSB;
    buff[1] = serAvailLSB;

    Wire.write(buff, 2); // Return the available bytes in MSB, LSB format

    // Reset last_address to zero
    last_address = 0;
  }
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

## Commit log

2020-05-30 Initial commit based on the PaulZC and SparkfunX repos
    [Qwiic_Iridium_9603N-Panel.GBL, Qwiic_Iridium_9603N-Panel.GBO, Qwiic_Iridium_9603N-Panel.GBS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]
2020-06-01 Adding x02 regular and production files.
    [Qwiic_Iridium_9603N-Panel.GBL, Qwiic_Iridium_9603N-Panel.GBO, Qwiic_Iridium_9603N-Panel.GBS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]

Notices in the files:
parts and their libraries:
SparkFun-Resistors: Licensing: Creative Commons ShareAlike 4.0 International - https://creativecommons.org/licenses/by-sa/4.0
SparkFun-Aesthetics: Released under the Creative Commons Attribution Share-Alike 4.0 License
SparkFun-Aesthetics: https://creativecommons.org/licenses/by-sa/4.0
